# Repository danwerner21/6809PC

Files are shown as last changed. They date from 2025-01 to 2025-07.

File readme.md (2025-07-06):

# 6809PC
The 6809PC is a 6809 ATX format board with 512K RAM, 4K ROM, with a flexible programmable MMU, battery backed up RTC, 6551 UART, and 6 ISAish slots.  This computer will run the fantastic CUBIX operating system by Dave Dunfield.  

See this repo (https://github.com/danwerner21/CUBIX09) for ROM image and operating system.

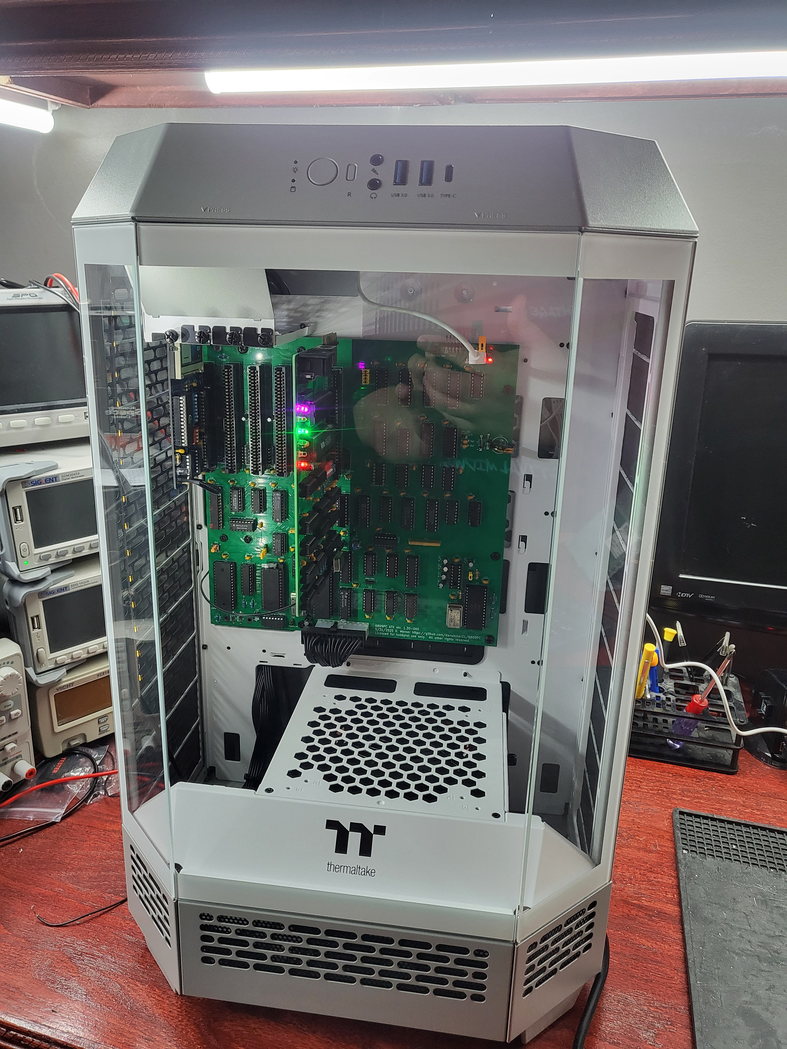
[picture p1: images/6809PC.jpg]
System


## BUGS
I have not built the 1.31 version, but it contains fixes for the only bug found in the 1.30 version which was in the ATX power switch circuit. The ICs in that circuit were not powered by standby power, they were powered by +5 which made them non-functional. Also the reset line on the ISA bus has the wrong polarity -- it should be active high.  There are no known remaining bugs in the 1.31 board.

### Jumper Settings
J1,J2,J5,J7,J9,J13 - ISA SLOT IRQ Selection
J11 - TTL Serial Port Connection
J12 - TTL Console Power

K1 - ROM BANK Selection (2-3 high bank, 1-2 Low Bank)
K2 - MMU Selection (1-2 Disable on int, 3-4 Clear Task register on int)

JP1 - Reset Swithc Connection
JP3 - CTS Pull Up Enable

P12 - Power Switch Connection
P15 - CPU Speed Selection
P18 - Serial Port Connection

### Building the system

### Default Memory Map
            $0000-$E000 - RAM
            $E000-$EFFF - Memory Mapped IO
            $F000-$FFFF - ROM

### Bill Of Materials
Reference|Value|Qty|Field1|Description
---------|-----|---|------|-----------
C1-C4,C17|22 uF|5||Polarized capacitor
C5-C16,C18-C27,C29-C33,C36-C54,C56,C58,C62|0.1 uF|49||Unpolarized capacitor
C28|1uF|1||Polarized capacitor
C35|10uF|1||Polarized capacitor
C57|0.01 uF|1||Unpolarized capacitor
C59,C60|15pf|2||Unpolarized capacitor
C61,C63-C66|1.0 uF|5||Polarized capacitor
D1,D2|1N4148|2||Diode
D3,D4|D|2||Diode
J1,J2,J5,J7,J9,J13|IRQ Selection|6||Generic connector, double row, 02x06, odd/even pin numbering scheme (row 1 odd numbers, row 2 even numbers), script generated (kicad-library-utils/schlib/autogen/connector/)
J3,J4,J6,J8,J10,J14|Bus_ISA_8bit|6||8-bit ISA-PC bus connector
J11|TTL SERIAL CONSOLE|1||Generic connector, single row, 01x06, script generated (kicad-library-utils/schlib/autogen/connector/)
J12|TTL CONSOLE PWR|1||Generic connector, single row, 01x02, script generated (kicad-library-utils/schlib/autogen/connector/)
JP1,JP3|JUMPER|2||-- mixed values --
K1|ROM SELECT|1||Generic connector, single row, 01x03, script generated (kicad-library-utils/schlib/autogen/connector/)
K2|MMU-INTA|1||Generic connector, single row, 01x03, script generated (kicad-library-utils/schlib/autogen/connector/)
P1|SHADOW ADDR|1||Generic connector, double row, 02x04, odd/even pin numbering scheme (row 1 odd numbers, row 2 even numbers), script generated (kicad-library-utils/schlib/autogen/connector/)
P11|CONN_10X2|1||Generic connector, double row, 02x10, odd/even pin numbering scheme (row 1 odd numbers, row 2 even numbers), script generated (kicad-library-utils/schlib/autogen/connector/)
P12|POWER_SW|1||Generic connector, single row, 01x02, script generated (kicad-library-utils/schlib/autogen/connector/)
P13|14.31818 MHz CLK|1||
P14|16.000Mhz|1||
P15|CPU CLOCK SPEED|1||Generic connector, double row, 02x04, odd/even pin numbering scheme (row 1 odd numbers, row 2 even numbers), script generated (kicad-library-utils/schlib/autogen/connector/)
P16|CONN_4|1||Generic connector, single row, 01x04, script generated (kicad-library-utils/schlib/autogen/connector/)
P17|1.8432 MHz CLK|1||
P18|SERIAL|1||Generic connector, double row, 02x05, odd/even pin numbering scheme (row 1 odd numbers, row 2 even numbers), script generated (kicad-library-utils/schlib/autogen/connector/)
R1,R3|10k|2||Resistor
R2|470|1||Resistor
R4,R7,R26|4.7K|3||Resistor
R5,R6,R8|1000|3||Resistor
RR1|2200|1||9 resistor network, star topology, bussed resistors, small symbol
RR2|22K|1||9 resistor network, star topology, bussed resistors, small symbol
SW1|POWER|1||Push button switch, generic, two pins
SW2|RESET|1||Push button switch, generic, two pins
U1|74LS04|1||Hex Inverter
U2,U34,U36,U39,U45,U46|74LS244|6||Octal Buffer and Line Driver With 3-State Output, active-low enables, non-inverting outputs
U3|74LS682|1||
U4|74LS86|1||Quad 2-input XOR
U5|74LS02|1||quad 2-input NOR gate
U6,U21|74LS00|2||quad 2-input NAND gate
U7,U10,U16|74LS32|3||Quad 2-input OR
U8|SRAM_512K|1||512K x 8 Low Power CMOS RAM, DIP-32
U9,U15|74LS08|2||Quad And2
U11|27C256|1||OTP EPROM 256 KiBit
U12,U22|74LS74|2||Dual D Flip-flop, Set & Reset
U17|74LS14|1||Hex inverter schmitt trigger
U18|74LS06|1||Inverter Open Collect
U19|74HCT14|1||Hex inverter schmitt trigger
U23|74LS688|1||8-bit magnitude comparator
U24,U42|74LS138|2||Decoder 3 to 8 active low outputs
U25-U28,U32,U41|74LS245|6||Octal BUS Transceivers, 3-State outputs
U29|DS1233|1||
U30|74LS163|1||Synchronous 4-bit programmable binary Counter
U31|74LS240|1||Octal Buffer and Line Driver With 3-State Output, active-low enables, inverting outputs
U33|MC68B09|1||8-Bit Microprocessing unit 2.0MHz, DIP-40
U35|74LS174|1||Hex D-type Flip-Flop, reset
U37|74LS157|1||Quad 2 to 1 line Multiplexer
U38|74LS374|1||8-bit Register, 3-state outputs
U40|SRAM-32K|1||256K (32K x 8) Static RAM, 70ns, DIP-28
U43,U44|74LS257|2||Quad 2 to 1 Multiplexer
U47|M6242|1||M6242
U48|G65SC51P|1||CMOS Asynchronous Communication Interface Adapter (ACIA), Serial UART, DIP-28
U49|MAX232|1||Dual RS232 driver/receiver, 5V supply, 120kb/s, 0C-70C
X1|RTC_OSC|1|32.768 KHz|Two pin crystal

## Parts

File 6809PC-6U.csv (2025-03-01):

Reference | Value | Datasheet | Footprint | Qty | DNP
C1,C2,C3,C4 | 22 uF | ~ | Custom:STD_DDW_PCAP | 4
C5,C6,C7,C8,C9,C10,C11,C12,C13,C14,C15,C16,C17,C18,C19,C20,C21,C22,C23,C24,C25,C26,C27,C29,C30,C31,C32,C33,C34,C36,C37,C38,C39,C40,C41,C42,C43,C44,C45,C46,C47,C48,C49,C50,C51,C52,C53,C54,C55,C56,C58,C62 | 0.1 uF | ~ | Custom:STD_DDW_CAP | 52
C28 | 1uF | ~ | Custom:STD_DDW_PCAP | 1
C35 | 10uF | ~ | Custom:STD_DDW_PCAP | 1
C57 | 0.01 uF | ~ | Custom:STD_DDW_CAP | 1
C59,C60 | 15pf | ~ | Custom:STD_DDW_CAP | 2
C61,C63,C64,C65,C66 | 1.0 uF | ~ | Custom:STD_DDW_PCAP | 5
C67 | 0.1µF | ~ | Custom:STD_DDW_CAP | 1
C68 | 10µF | ~ | Custom:STD_DDW_PCAP | 1
D1,D2 | 1N4148 | ~ | Custom:STD_DDW_DIODE | 2
D3,D4 | D | ~ | Custom:STD_DDW_DIODE | 2
D5,D6 | 1N4001 | http://www.vishay.com/docs/88503/1n4001.pdf | Custom:STD_DDW_DIODE | 2
J1,J2,J5,J7,J9 | IRQ Selection | ~ | Custom:STD_DDW_PINHEAD_V_2x06 | 5
J3,J4,J6,J8,J10 | Bus_ISA_8bit | https://en.wikipedia.org/wiki/Industry_Standard_Architecture | Custom:BUSPC_HOST | 5
J11 | TTL SERIAL CONSOLE | ~ | Custom:STD_DDW_PINHEAD_V_1x06 | 1
J12 | TTL CONSOLE PWR | ~ | Custom:STD_DDW_PINHEAD_V_1x02 | 1
J13 | KEYBOARD AND MOUSE | ~ | Custom:STD_DDW_PINHEAD_V_2x05 | 1
J14,J15 | VGA | ~ | -- mixed values -- | 2
J16 | Keyboard | http://service.powerdynamics.com/ec/Catalog17/Section%2011.pdf | Custom:PS2_DIN | 1
J17 | Mouse | http://service.powerdynamics.com/ec/Catalog17/Section%2011.pdf | Custom:PS2_DIN | 1
J18 | AUDIO OUT | ~ | Custom:STD_DDW_PINHEAD_V_1x02 | 1
J19 | TTL SERIAL 0 | ~ | Custom:STD_DDW_PINHEAD_V_1x06 | 1
J20 | TTL SER 0 PWR | ~ | Custom:STD_DDW_PINHEAD_V_1x02 | 1
J21 | TTL SERIAL 1 | ~ | Custom:STD_DDW_PINHEAD_V_1x06 | 1
J22 | TTL SER 1 PWR | ~ | Custom:STD_DDW_PINHEAD_V_1x02 | 1
JP1,JP3 | JUMPER | ~ | Custom:STD_DDW_PINHEAD_V_1x02 | 2
JP2 | CPU XTAL | ~ | Custom:STD_DDW_PINHEAD_V_1x02 | 1
JP4 | OPT1 | ~ | Custom:STD_DDW_PINHEAD_V_1x02 | 1
JP5 | OPT2 | ~ | Custom:STD_DDW_PINHEAD_V_1x02 | 1
K1 | EPROM/FLASH | ~ | Custom:STD_DDW_PINHEAD_V_1x03 | 1
K2 | CONN_3 | ~ | Custom:STD_DDW_PINHEAD_V_1x03 | 1
K3 | P Port Power | ~ | Custom:STD_DDW_PINHEAD_V_1x03 | 1
P1 | SHADOW ADDR | ~ | Custom:STD_DDW_PINHEAD_V_2x04 | 1
P11 | CONN_10X2 | ~ | Custom:ATXConnector | 1
P12 | POWER_SW | ~ | Custom:STD_DDW_PINHEAD_V_1x02 | 1
P13 | 14.31818 MHz CLK |  | Custom:STD_DDW_DIP14 | 1
P14 | 16.000Mhz |  | Custom:STD_DDW_DIP14 | 1
P15 | CPU CLOCK SPEED | ~ | Custom:STD_DDW_PINHEAD_V_2x04 | 1
P16 | CONN_4 | ~ | Custom:STD_DDW_PINHEAD_V_1x04 | 1
P17 | 1.8432 MHz CLK |  | Custom:STD_DDW_DIP14 | 1
P18 | SERIAL | ~ | Custom:STD_DDW_PINHEAD_V_2x05 | 1
P19 | VIA OUTPUT | ~ | Custom:STD_DDW_PINHEAD_V_2x08 | 1
P20 | PARALLEL | ~ | Custom:STD_DDW_PINHEAD_V_2x13 | 1
R1,R3 | 10k | ~ | Custom:STD_DDW_RESISTOR | 2
R2 | 470 | ~ | Custom:STD_DDW_RESISTOR | 1
R4,R7 | 4.7K | ~ | Custom:STD_DDW_RESISTOR | 2
R5,R6 | 1000 | ~ | Custom:STD_DDW_RESISTOR | 2
R8,R10,R12 | 390Ω | ~ | Custom:STD_DDW_RESISTOR | 3
R9,R11,R13 | 820Ω | ~ | Custom:STD_DDW_RESISTOR | 3
R14,R15,R20,R21 | 120Ω | ~ | Custom:STD_DDW_RESISTOR | 4
R16,R18 | 2.2KΩ | ~ | Custom:STD_DDW_RESISTOR | 2
R17,R19,RN1 | 1KΩ | -- mixed values -- | -- mixed values -- | 3
R22 | 270Ω | ~ | Custom:STD_DDW_RESISTOR | 1
R23 | 150Ω | ~ | Custom:STD_DDW_RESISTOR | 1
R24,R25,RR2 | 22K | -- mixed values -- | -- mixed values -- | 3
RR1 | 2200 | http://www.vishay.com/docs/31509/csc.pdf | Custom:STD_DDW_SIP10 | 1
SW1 | POWER | ~ | Custom:STD_DDW_TACTSW | 1
SW2 | MOM CNCT | ~ | Custom:STD_DDW_TACTSW | 1
U1,U20 | 74LS04 | http://www.ti.com/lit/gpn/sn74LS04 | Custom:STD_DDW_DIP14 | 2
U2,U34,U36,U39,U45,U46,U56 | 74LS244 | http://www.ti.com/lit/ds/symlink/sn74ls244.pdf | Custom:STD_DDW_DIP20 | 7
U3 | 74LS682 |  | Custom:STD_DDW_DIP20 | 1
U4 | 74LS86 | 74xx/74ls86.pdf | Custom:STD_DDW_DIP14 | 1
U5 | 74LS02 | http://www.ti.com/lit/gpn/sn74ls02 | Custom:STD_DDW_DIP14 | 1
U6,U21 | 74LS00 | http://www.ti.com/lit/gpn/sn74ls00 | Custom:STD_DDW_DIP14 | 2
U7,U10,U11,U12,U16 | 74LS32 | http://www.ti.com/lit/gpn/sn74LS32 | Custom:STD_DDW_DIP14 | 5
U8 | SRAM_512K | https://www.alliancememory.com/wp-content/uploads/pdf/AS6C4008.pdf | Custom:STD_DDW_DIP32 | 1
U9 | 29F040 | http://ww1.microchip.com/downloads/en/DeviceDoc/25022B.pdf | Custom:STD_DDW_DIP32 | 1
U13,U14 | 74LS07 | www.ti.com/lit/ds/symlink/sn74ls07.pdf | Custom:STD_DDW_DIP14 | 2
U15 | 74LS08 | http://www.ti.com/lit/gpn/sn74LS08 | Custom:STD_DDW_DIP14 | 1
U17 | 74LS14 | http://www.ti.com/lit/gpn/sn74LS14 | Custom:STD_DDW_DIP14 | 1
U18 | 74LS06 | http://www.ti.com/lit/gpn/sn74LS06 | Custom:STD_DDW_DIP14 | 1
U19 | 74HCT14 | http://www.ti.com/lit/gpn/sn74LS14 | Custom:STD_DDW_DIP14 | 1
U22 | 74LS74 | 74xx/74hc_hct74.pdf | Custom:STD_DDW_DIP14 | 1
U23 | 74LS688 | http://www.ti.com/lit/gpn/sn74LS688 | Custom:STD_DDW_DIP20 | 1
U24,U42 | 74LS138 | http://www.ti.com/lit/gpn/sn74LS138 | Custom:STD_DDW_DIP16 | 2
U25,U26,U27,U28,U32,U41 | 74LS245 | http://www.ti.com/lit/gpn/sn74LS245 | Custom:STD_DDW_DIP20 | 6
U29 | DS1233 | ~ | Custom:STD_DDW_TO92 | 1
U30 | 74LS163 | http://www.ti.com/lit/gpn/sn74LS163 | Custom:STD_DDW_DIP16 | 1
U31 | 74LS240 | http://www.ti.com/lit/ds/symlink/sn74ls240.pdf | Custom:STD_DDW_DIP20 | 1
U33 | MC68B09 | http://pdf.datasheetcatalog.com/datasheet/motorola/MC68B09S.pdf | Custom:STD_DDW_DIP40 | 1
U35 | 74LS174 | http://www.ti.com/lit/gpn/sn74LS174 | Custom:STD_DDW_DIP16 | 1
U37 | 74LS157 | http://www.ti.com/lit/gpn/sn74LS157 | Custom:STD_DDW_DIP16 | 1
U38 | 74LS374 | http://www.ti.com/lit/gpn/sn74LS374 | Custom:STD_DDW_DIP20 | 1
U40 | SRAM-32K | https://ecee.colorado.edu/~mcclurel/Cypress_SRAM_CY62256.pdf | Custom:STD_DDW_DIP28_SKINNY | 1
U43,U44 | 74LS257 | http://www.ti.com/lit/gpn/sn74LS257 | Custom:STD_DDW_DIP16 | 2
U47 | ~ |  | Custom:STD_DDW_DIP18 | 1
U48 | G65SC51P | http://www.westerndesigncenter.com/wdc/documentation/w65c51n.pdf | Custom:STD_DDW_DIP28 | 1
U49 | MAX232 | http://www.ti.com/lit/ds/symlink/max232.pdf | Custom:STD_DDW_DIP16 | 1
U50,U52 | 74HC595 | http://www.ti.com/lit/ds/symlink/sn74hc595.pdf | Custom:STD_DDW_DIP16 | 2
U51,U53 | 74HC165 | https://assets.nexperia.com/documents/data-sheet/74HC_HCT165.pdf | Custom:STD_DDW_DIP16 | 2
U54,U55 | ESP32_MODULE |  | Custom:ESP32_Module | 2
U57,U58 | G65SC22P | http://www.westerndesigncenter.com/wdc/documentation/w65c22.pdf | Custom:STD_DDW_DIP40 | 2
X1 | RTC_OSC | ~ | Custom:DDW_STD_RTCCRYSTAL | 1

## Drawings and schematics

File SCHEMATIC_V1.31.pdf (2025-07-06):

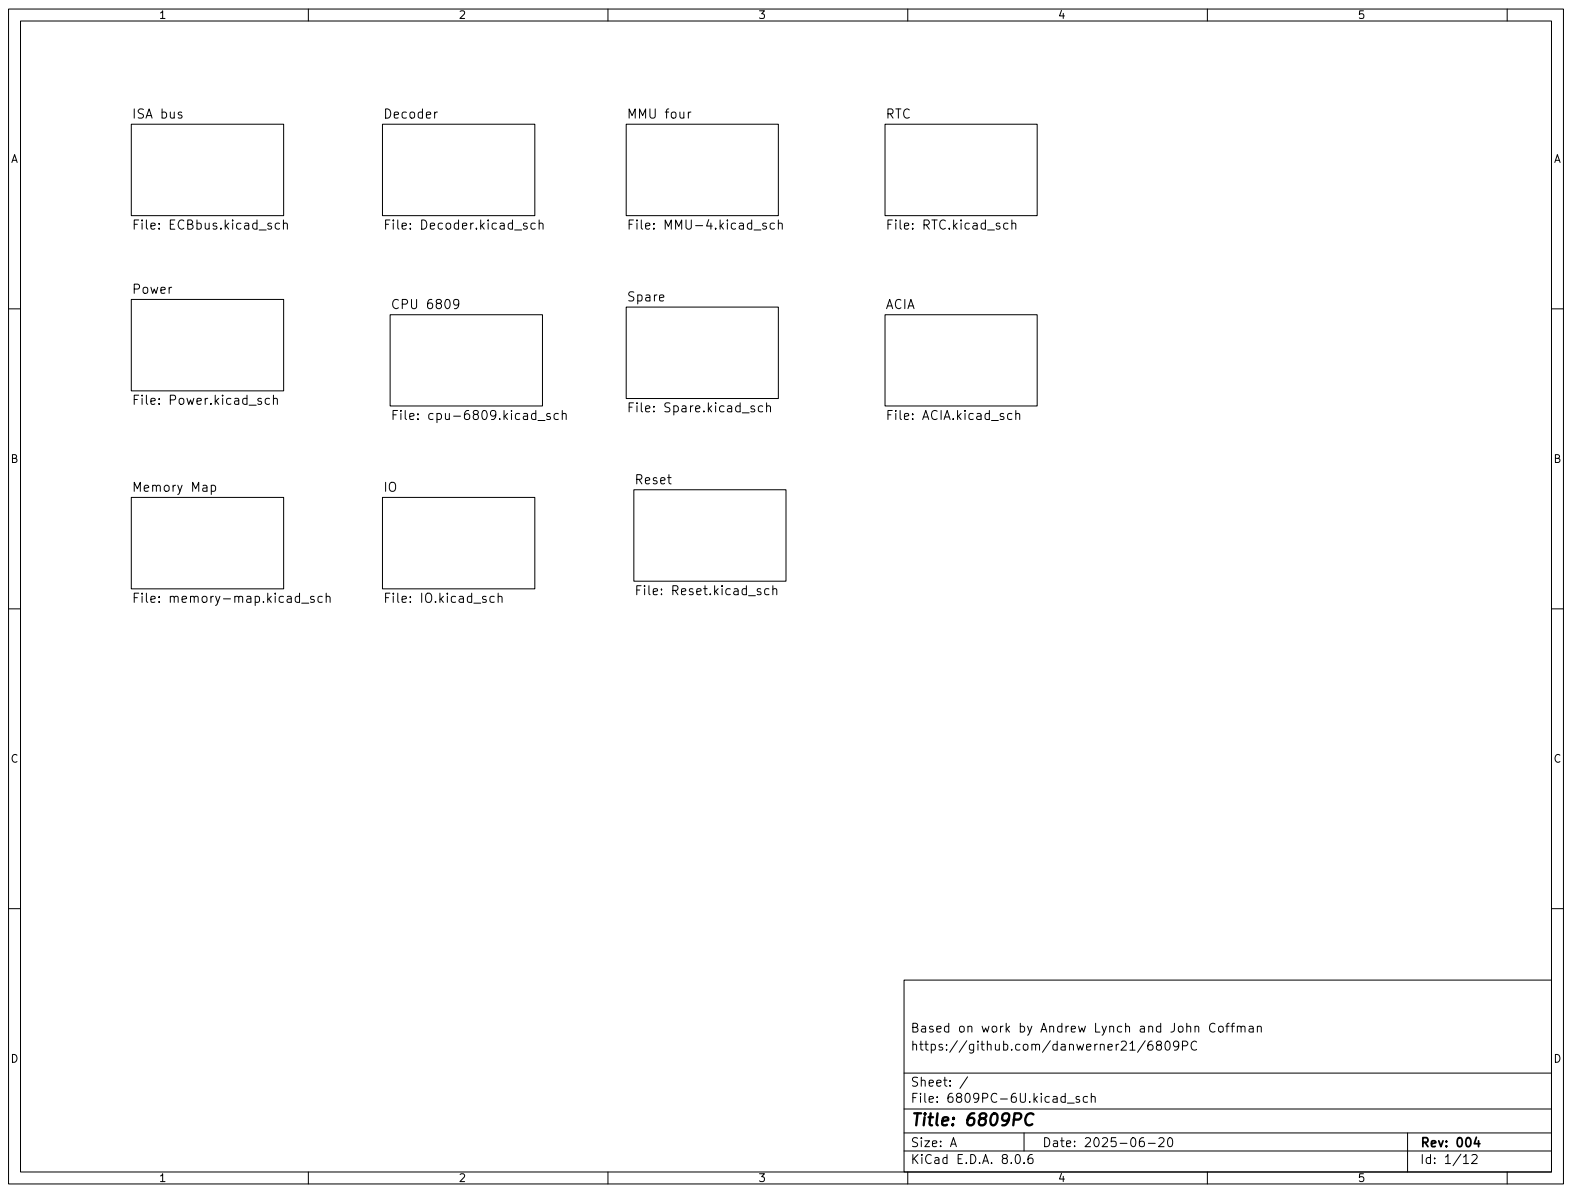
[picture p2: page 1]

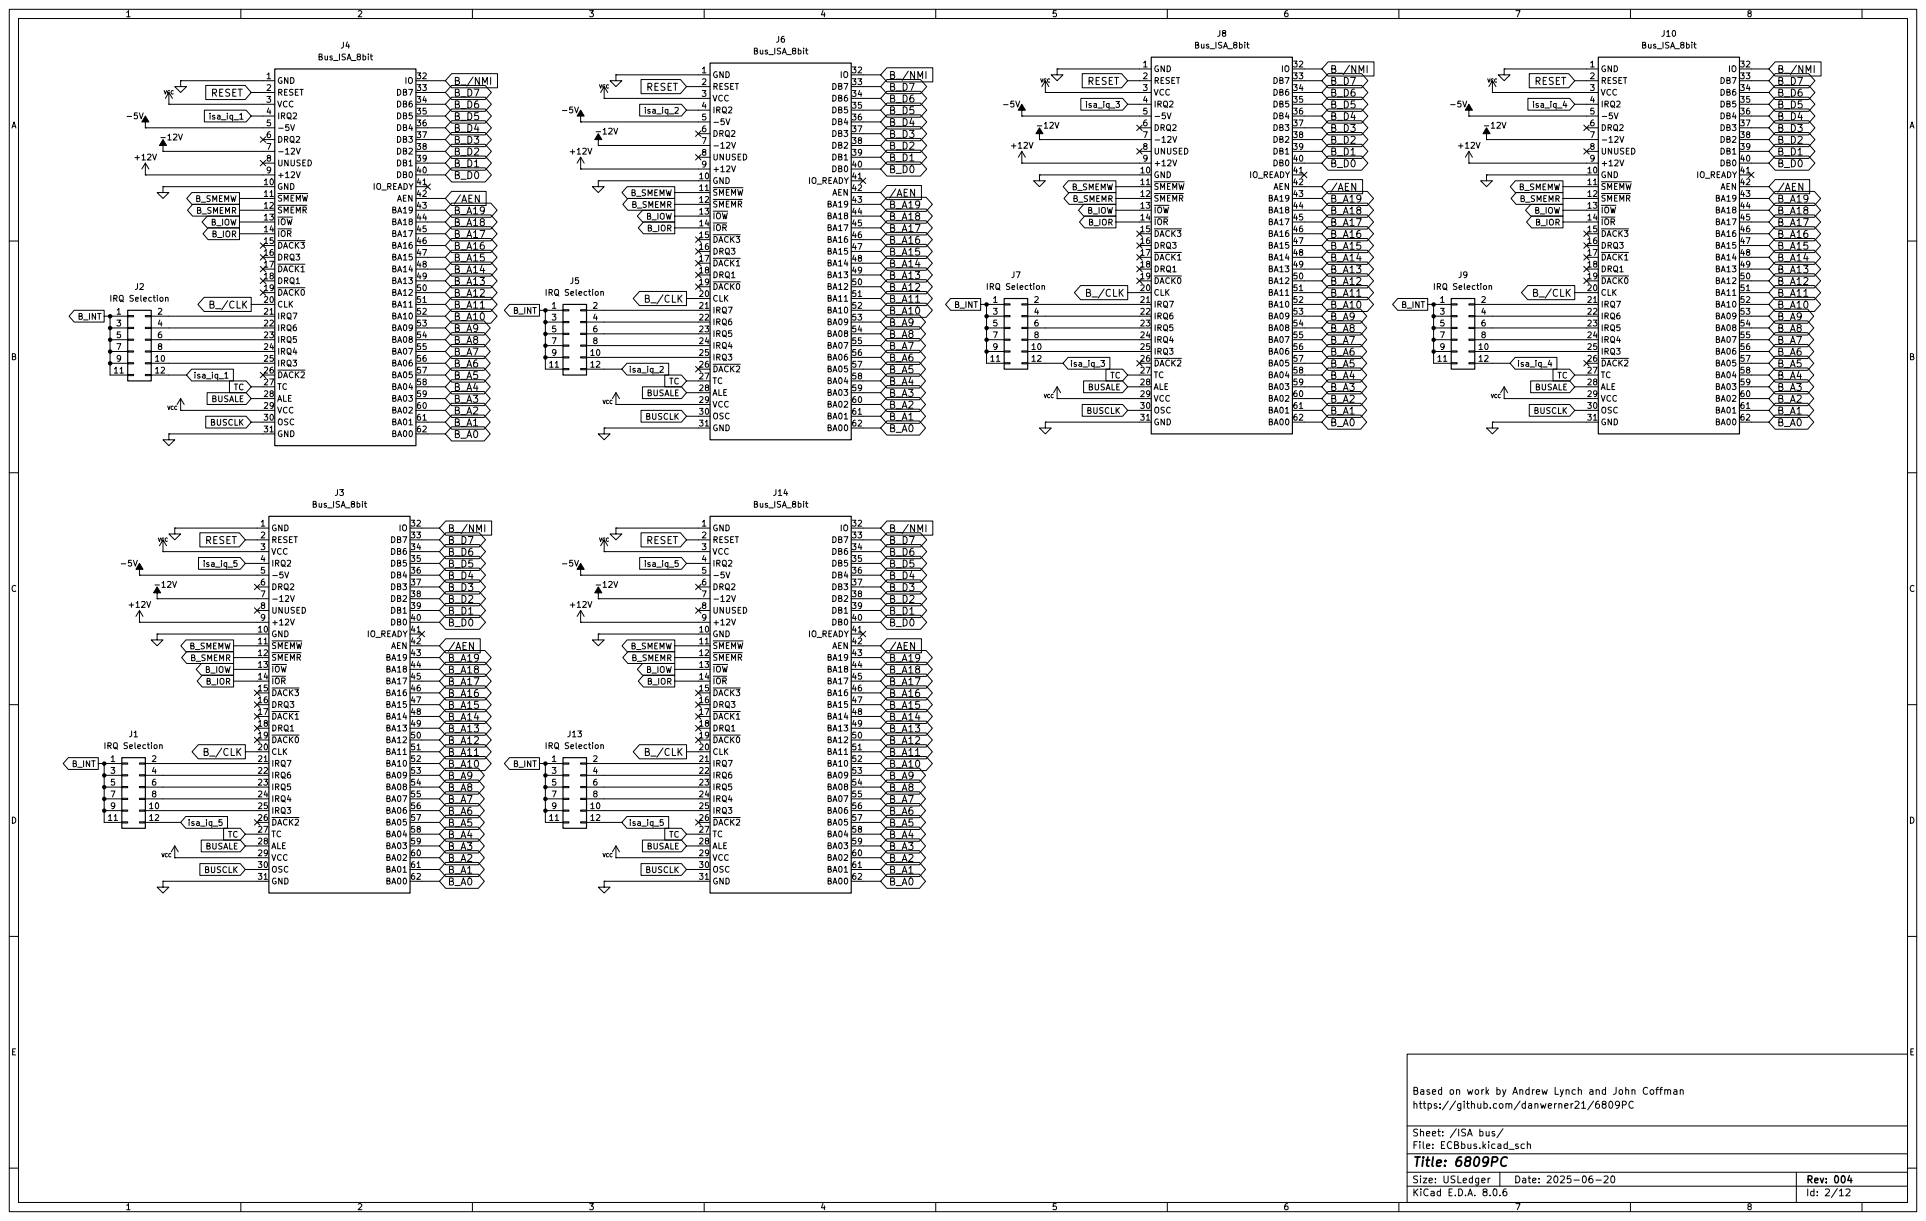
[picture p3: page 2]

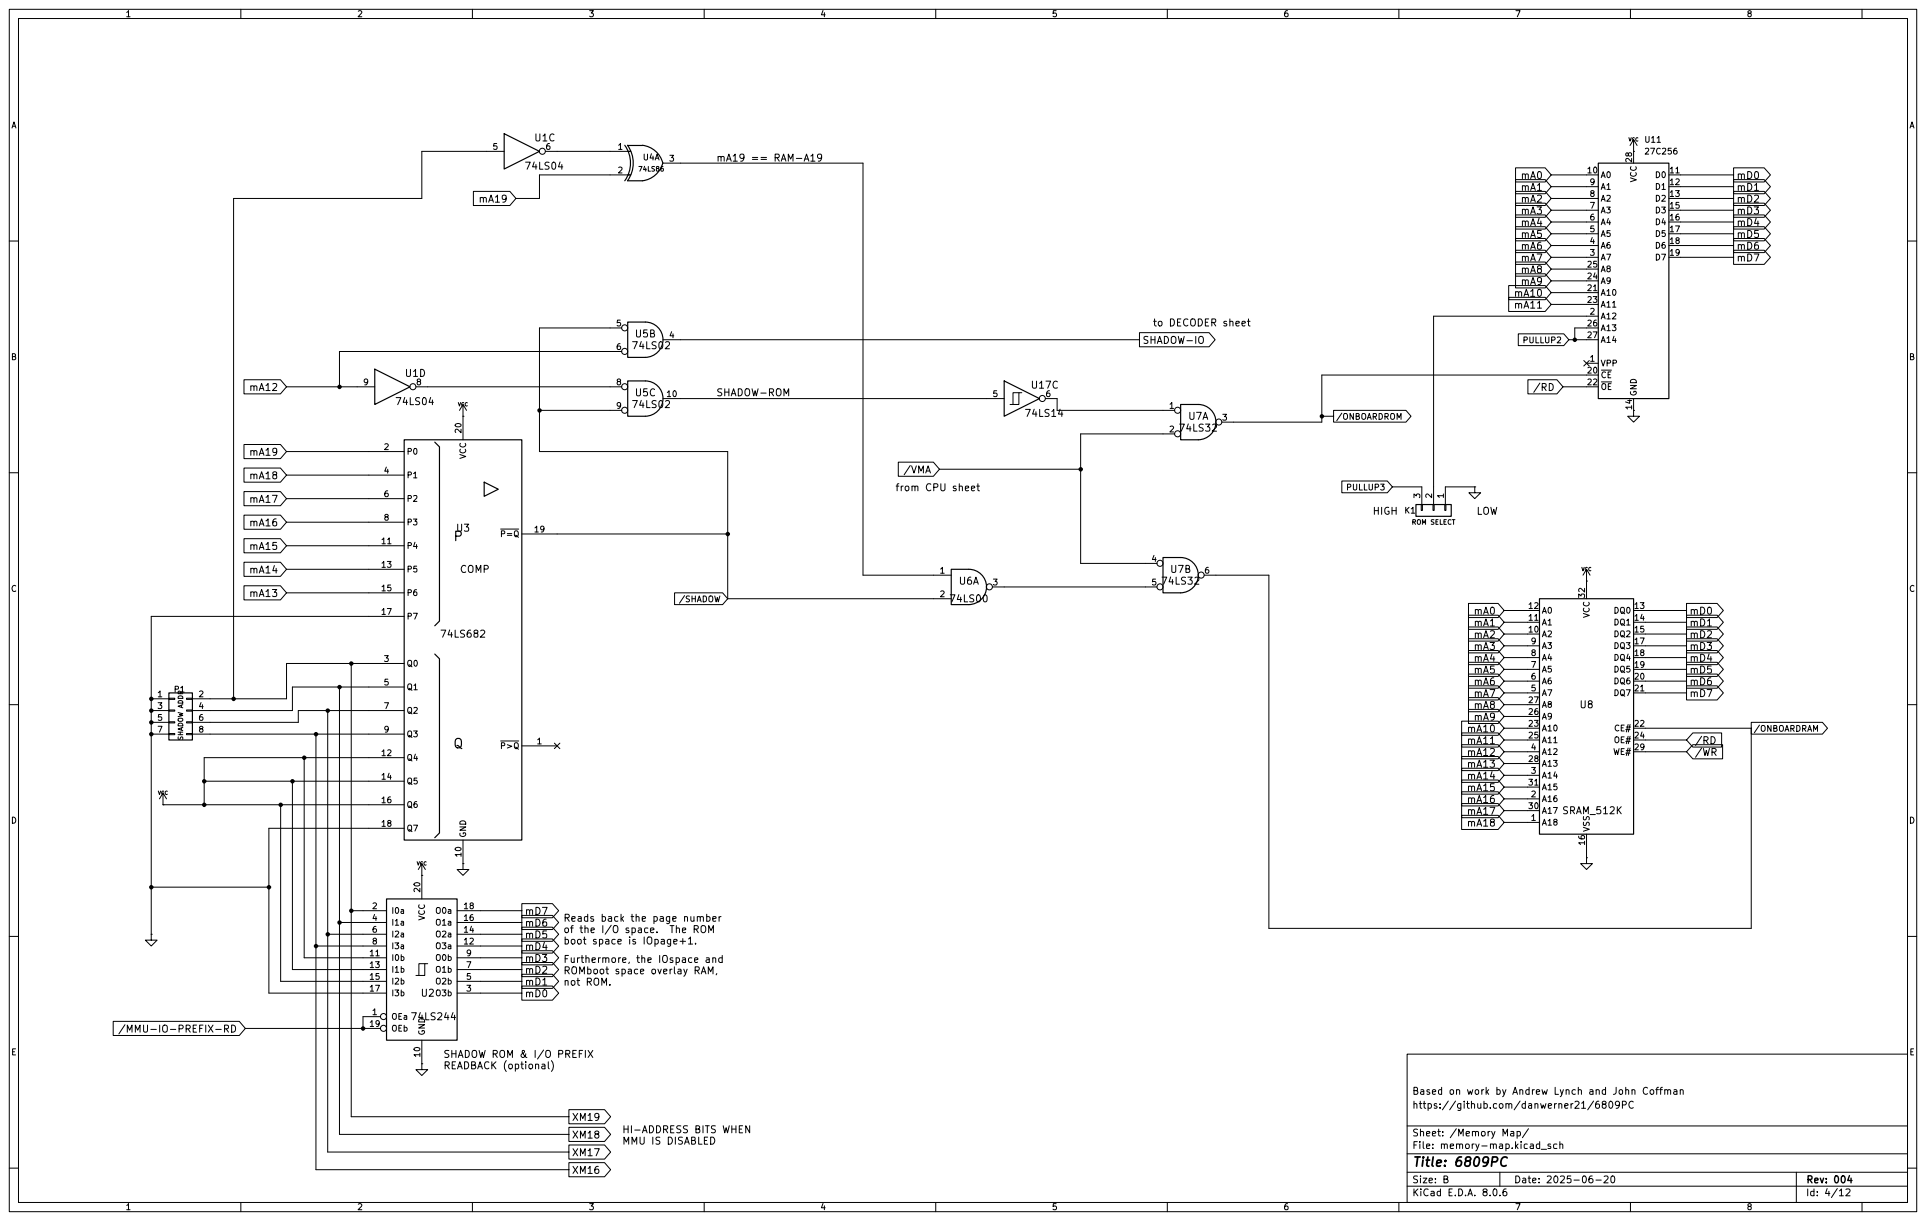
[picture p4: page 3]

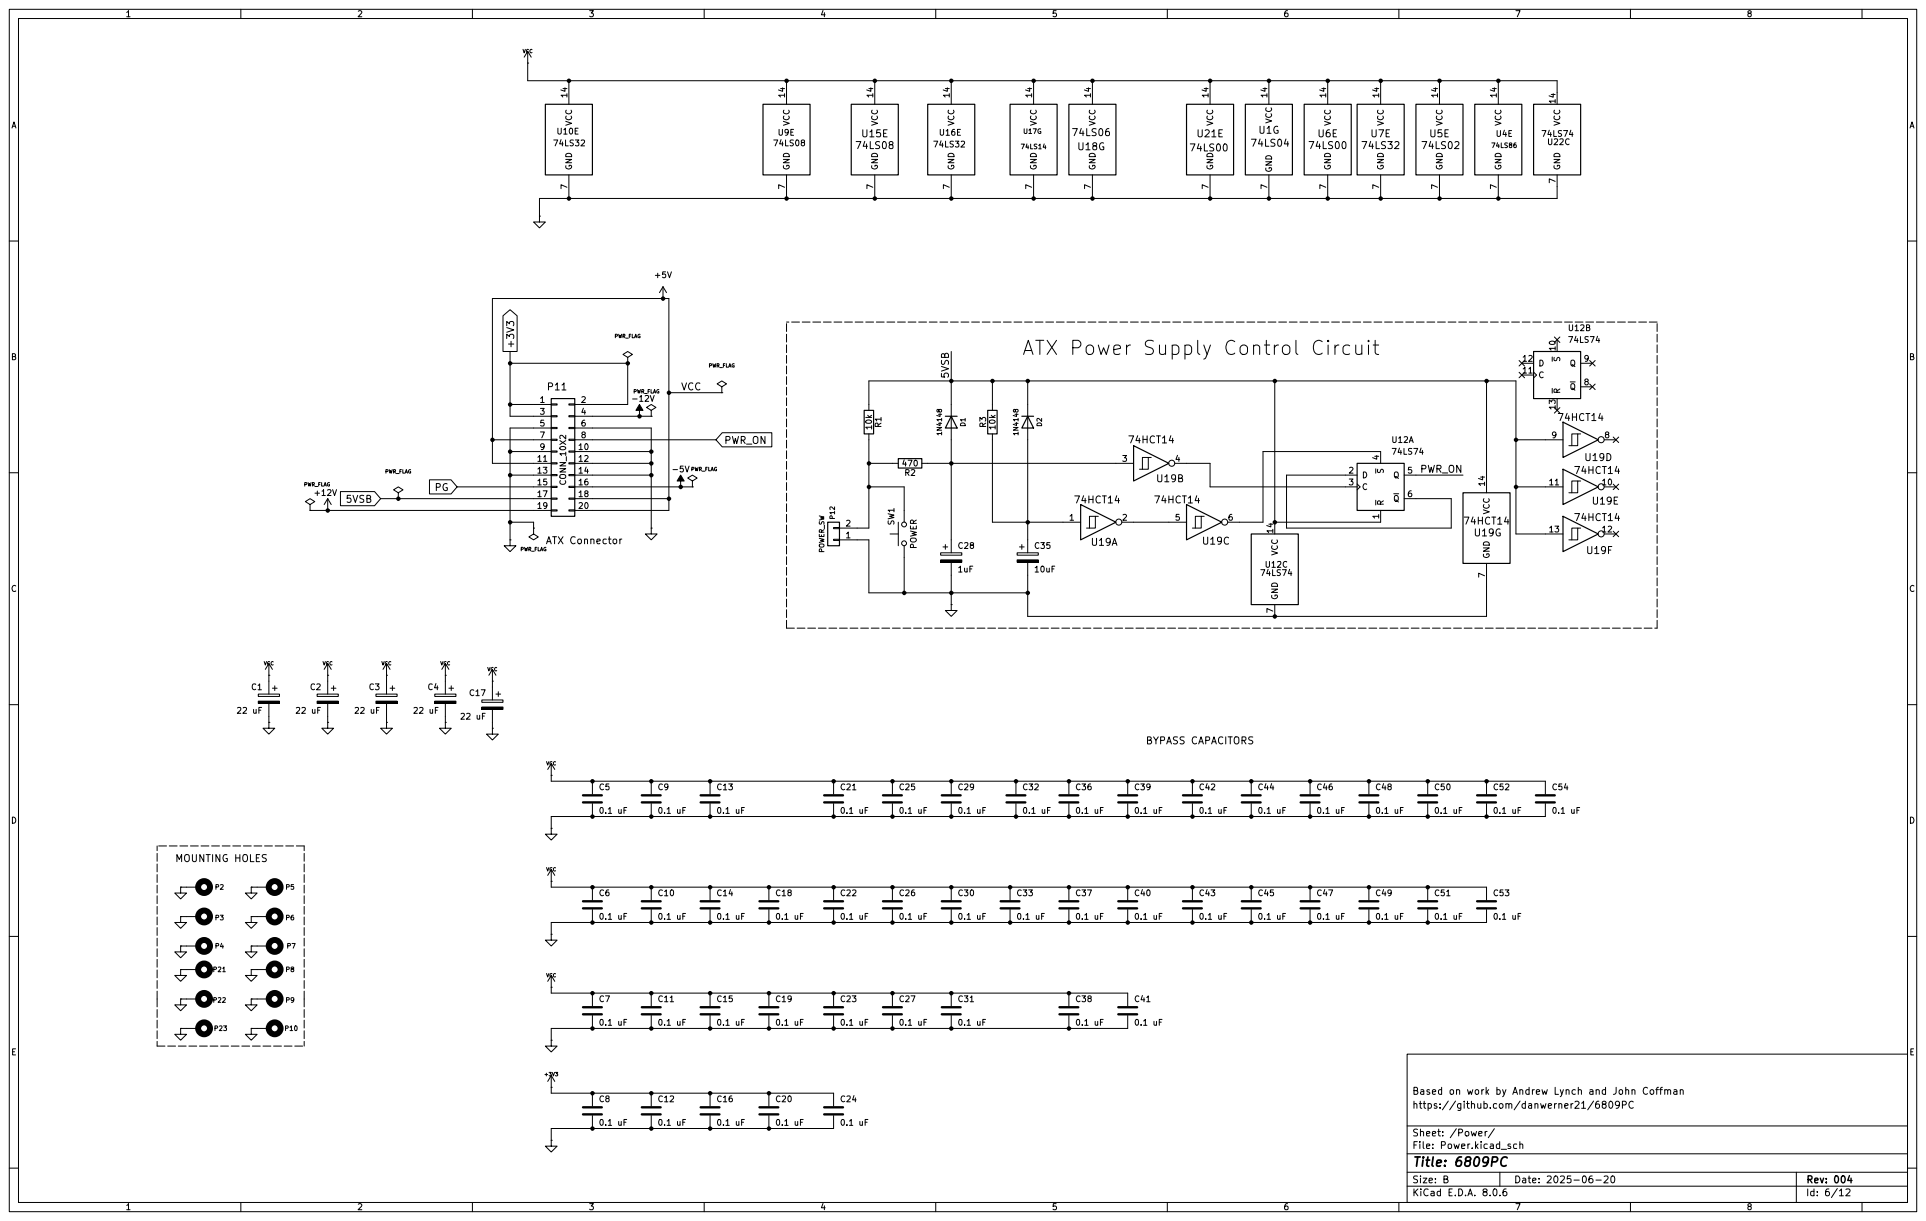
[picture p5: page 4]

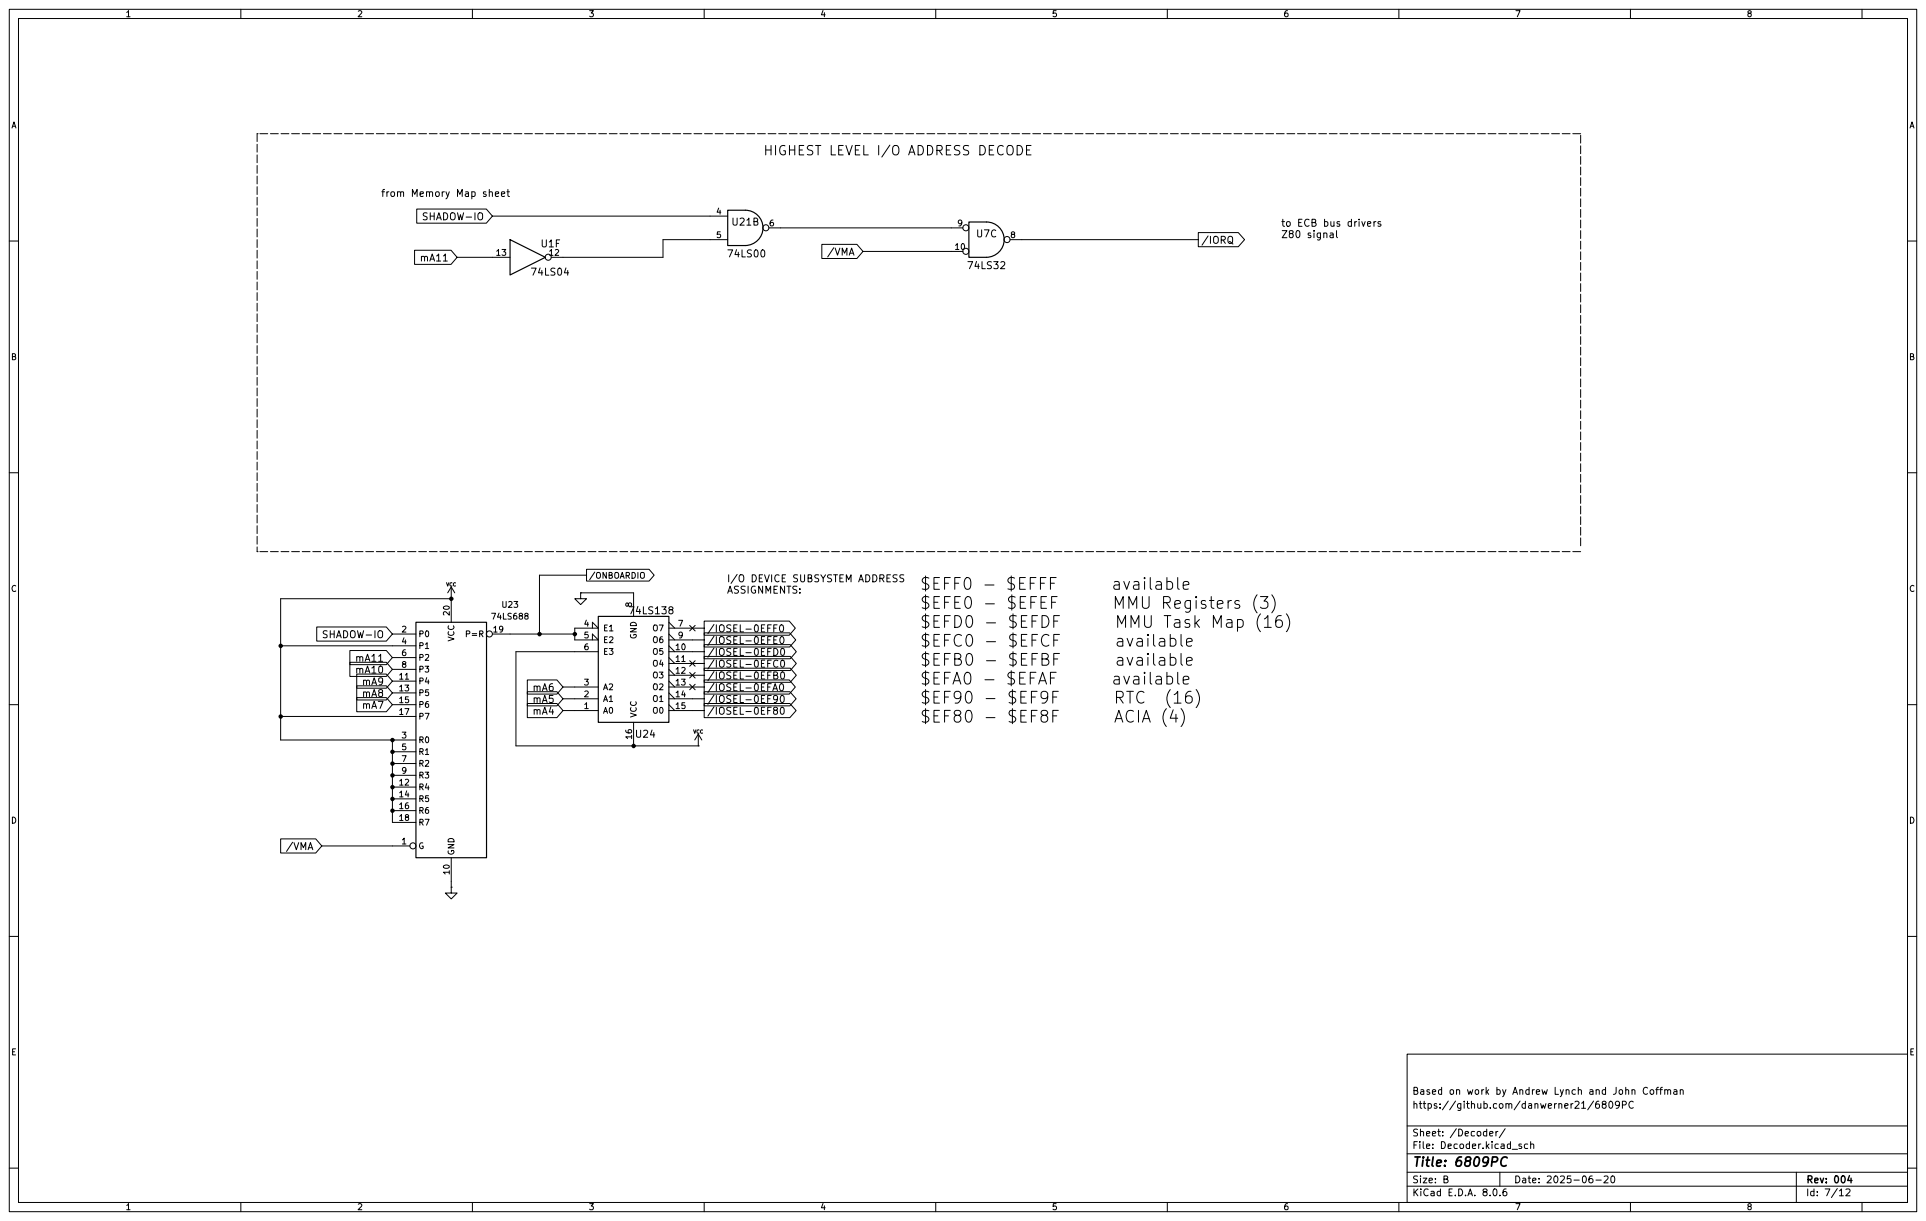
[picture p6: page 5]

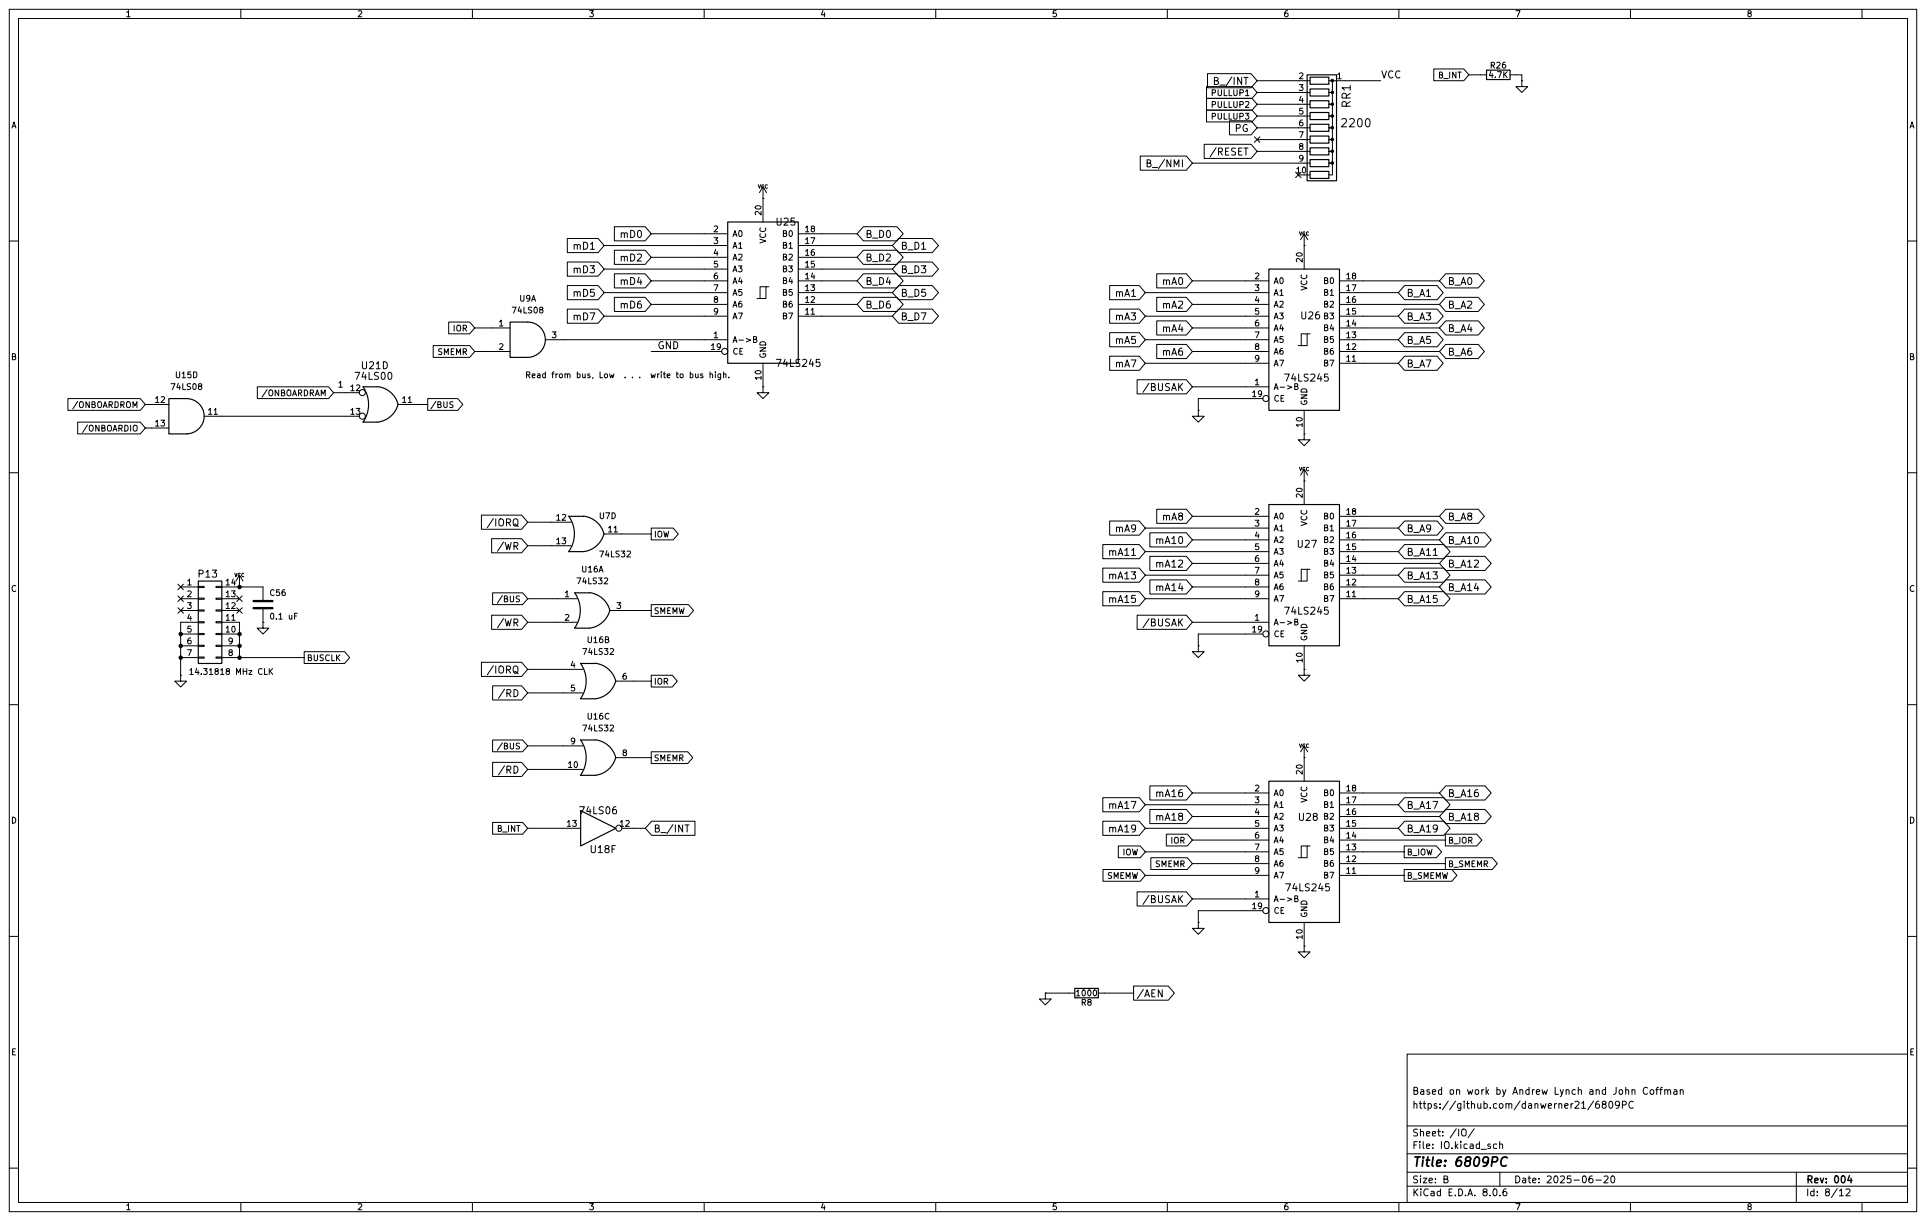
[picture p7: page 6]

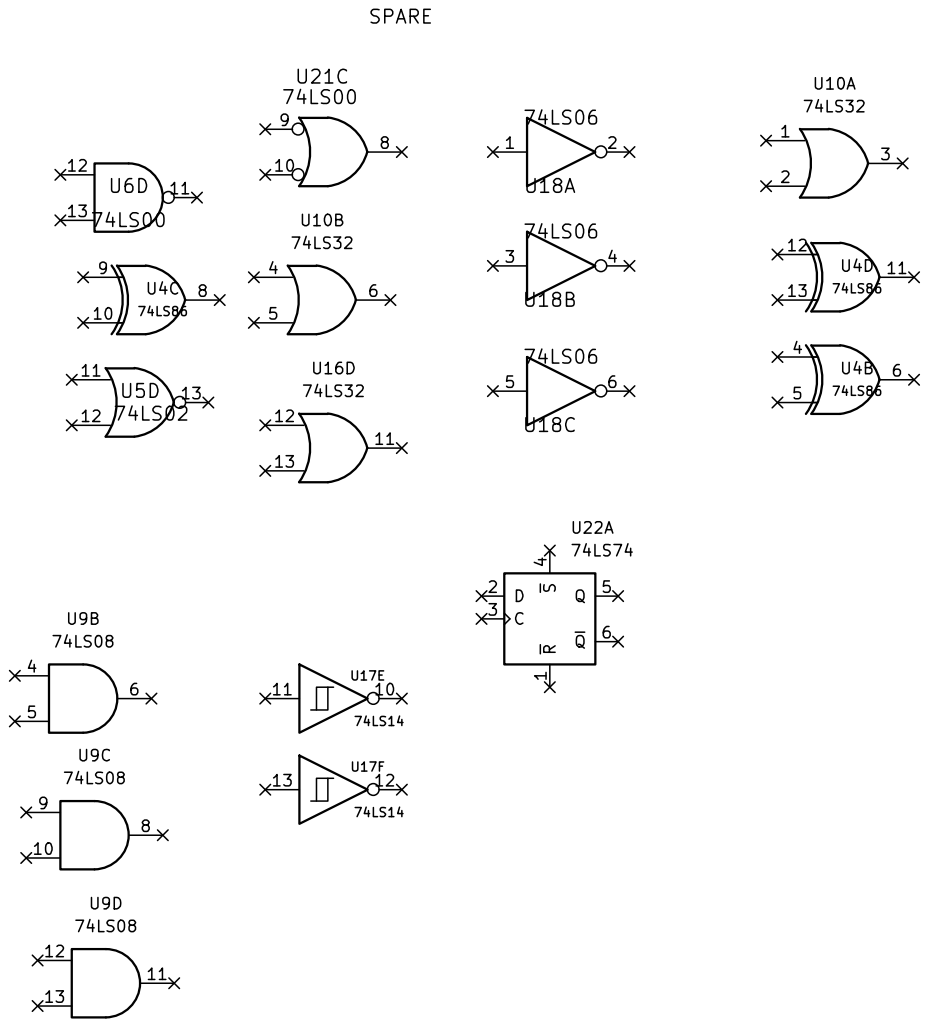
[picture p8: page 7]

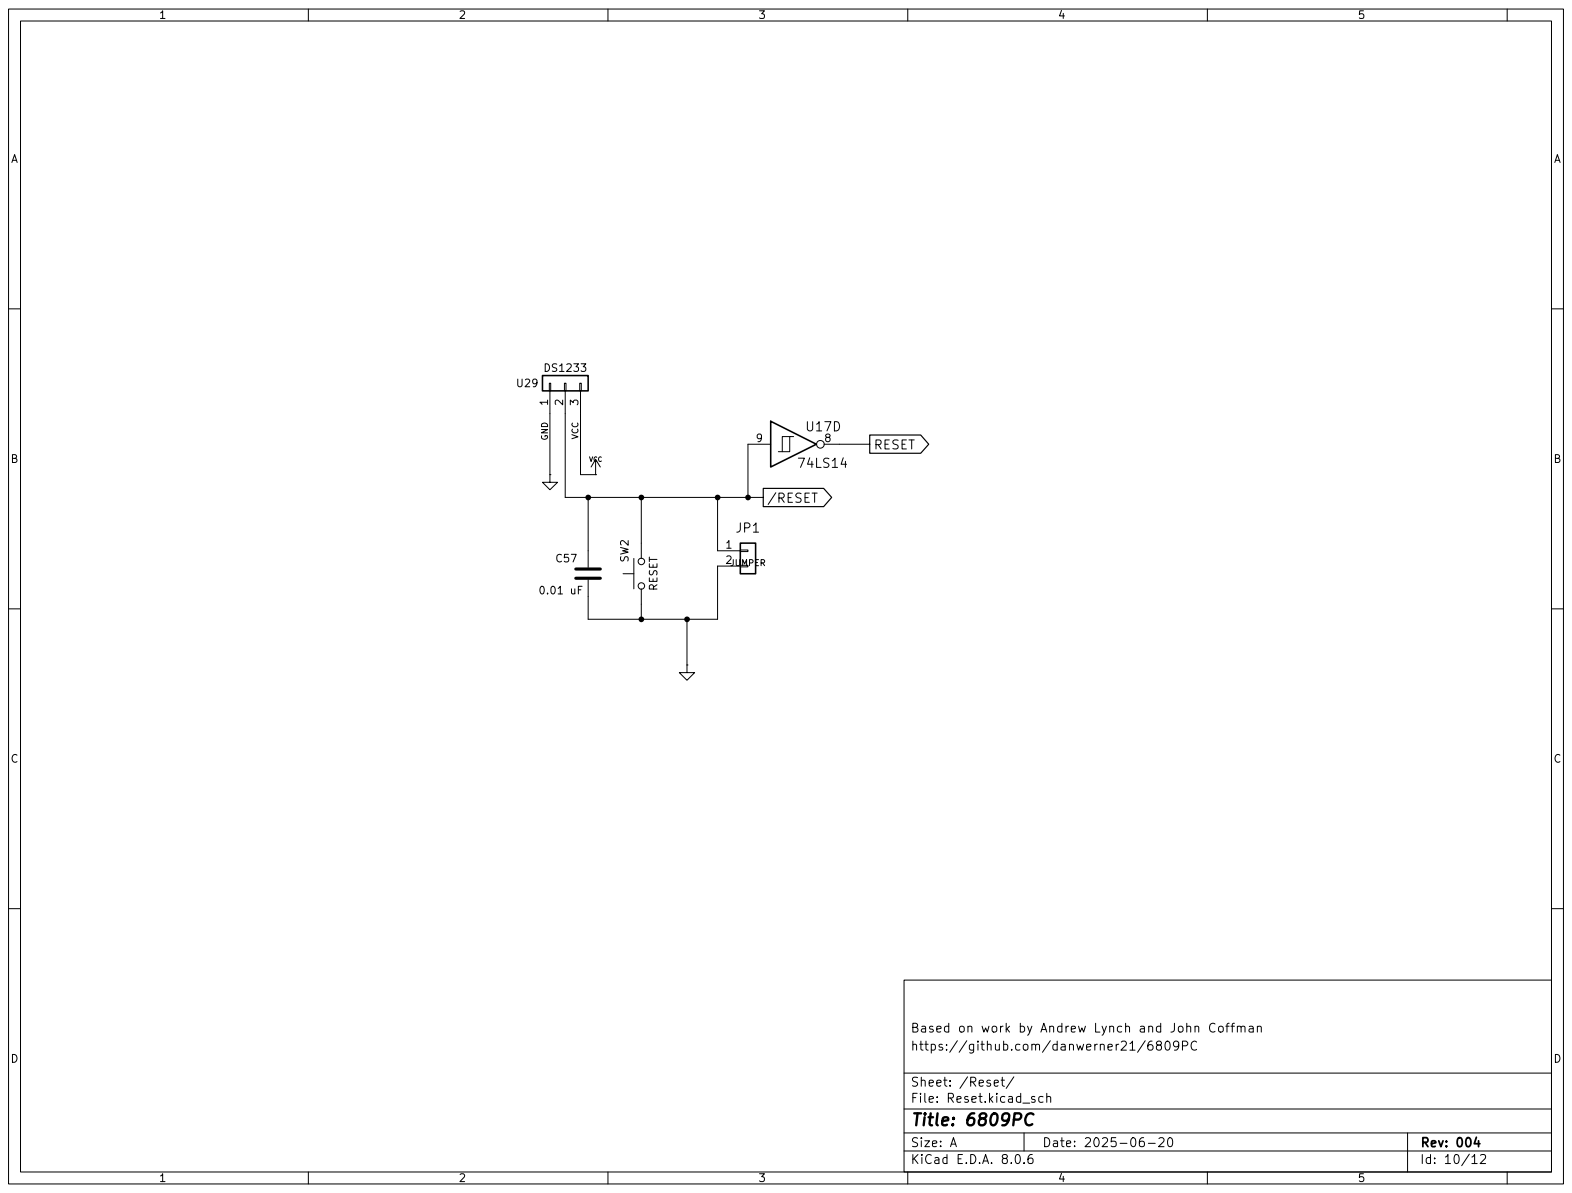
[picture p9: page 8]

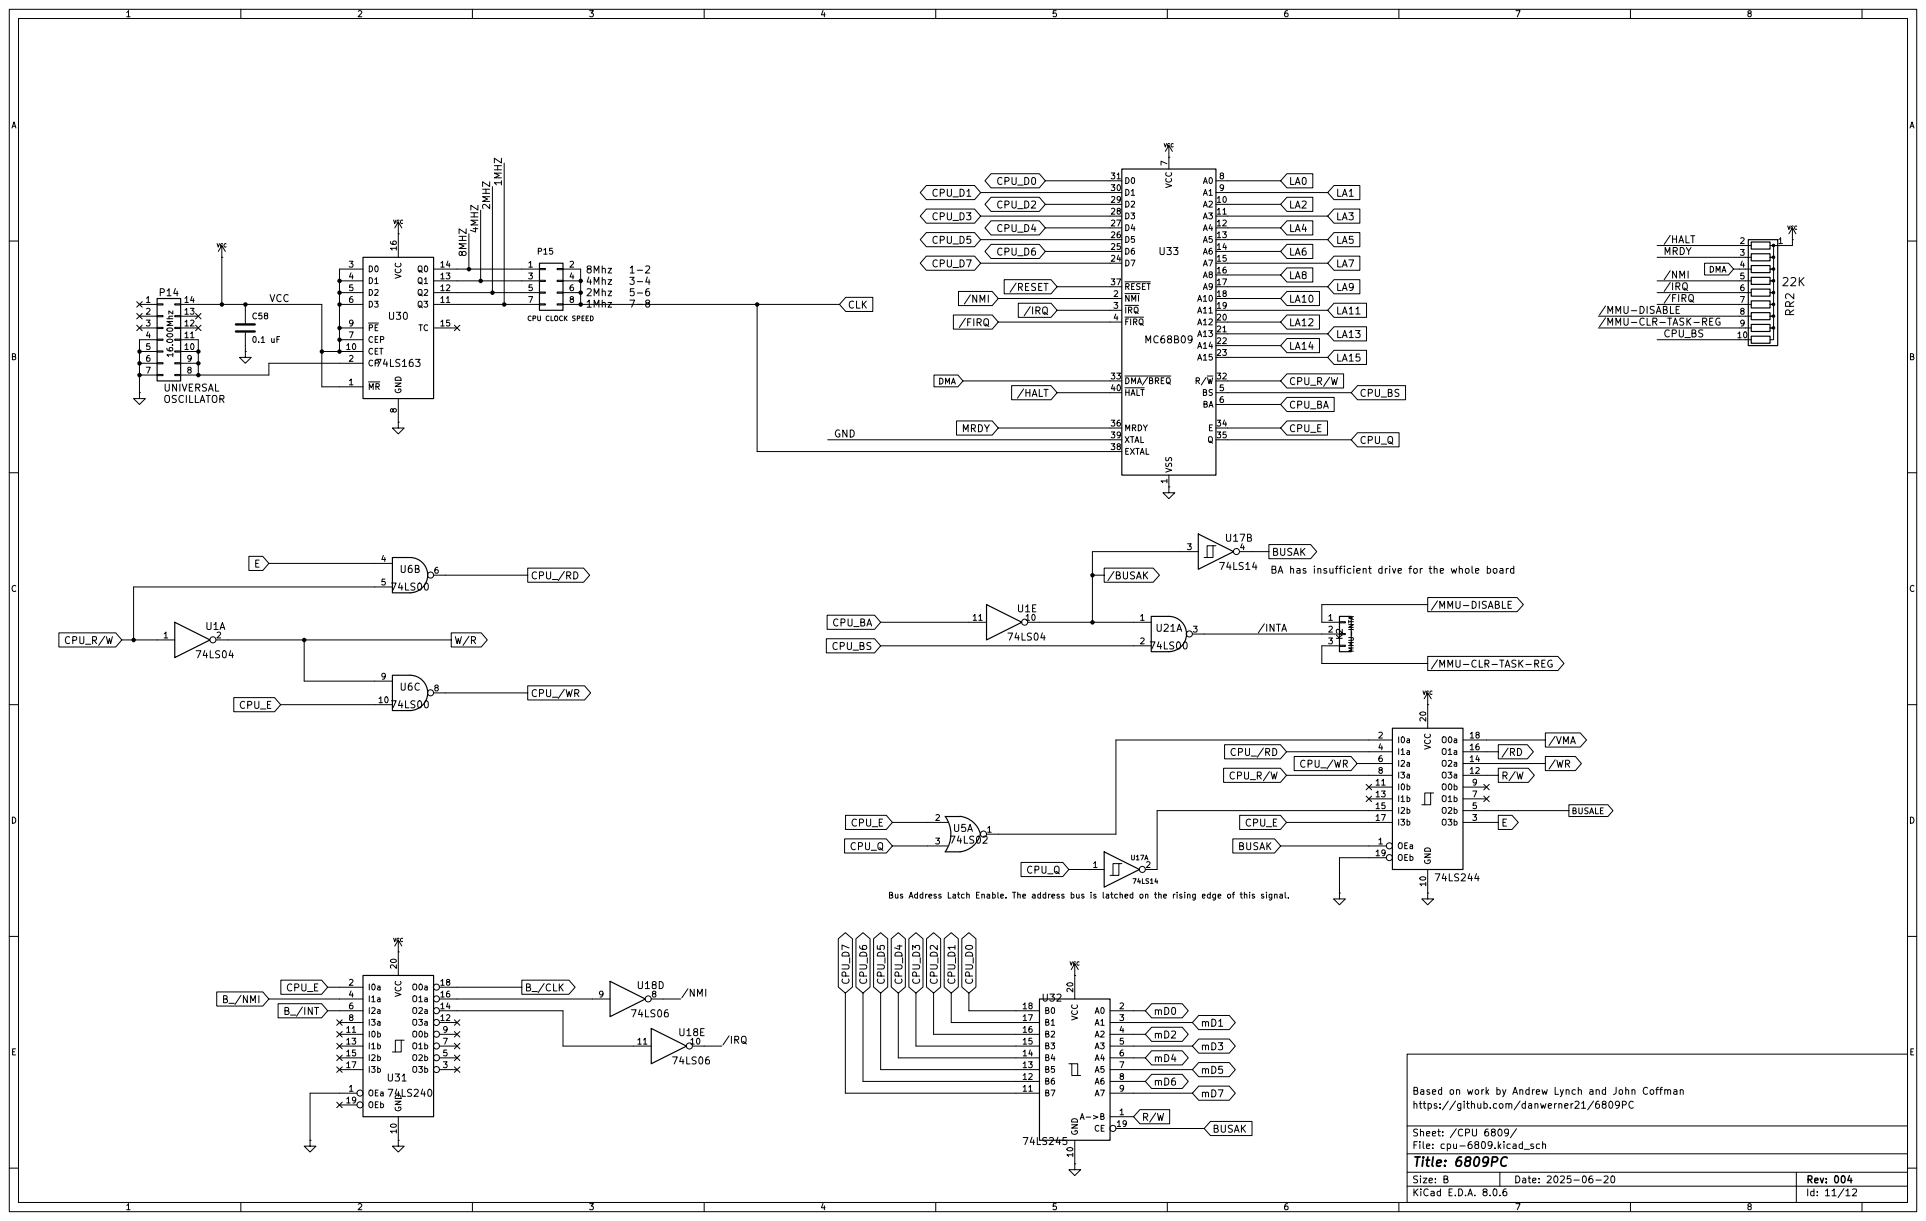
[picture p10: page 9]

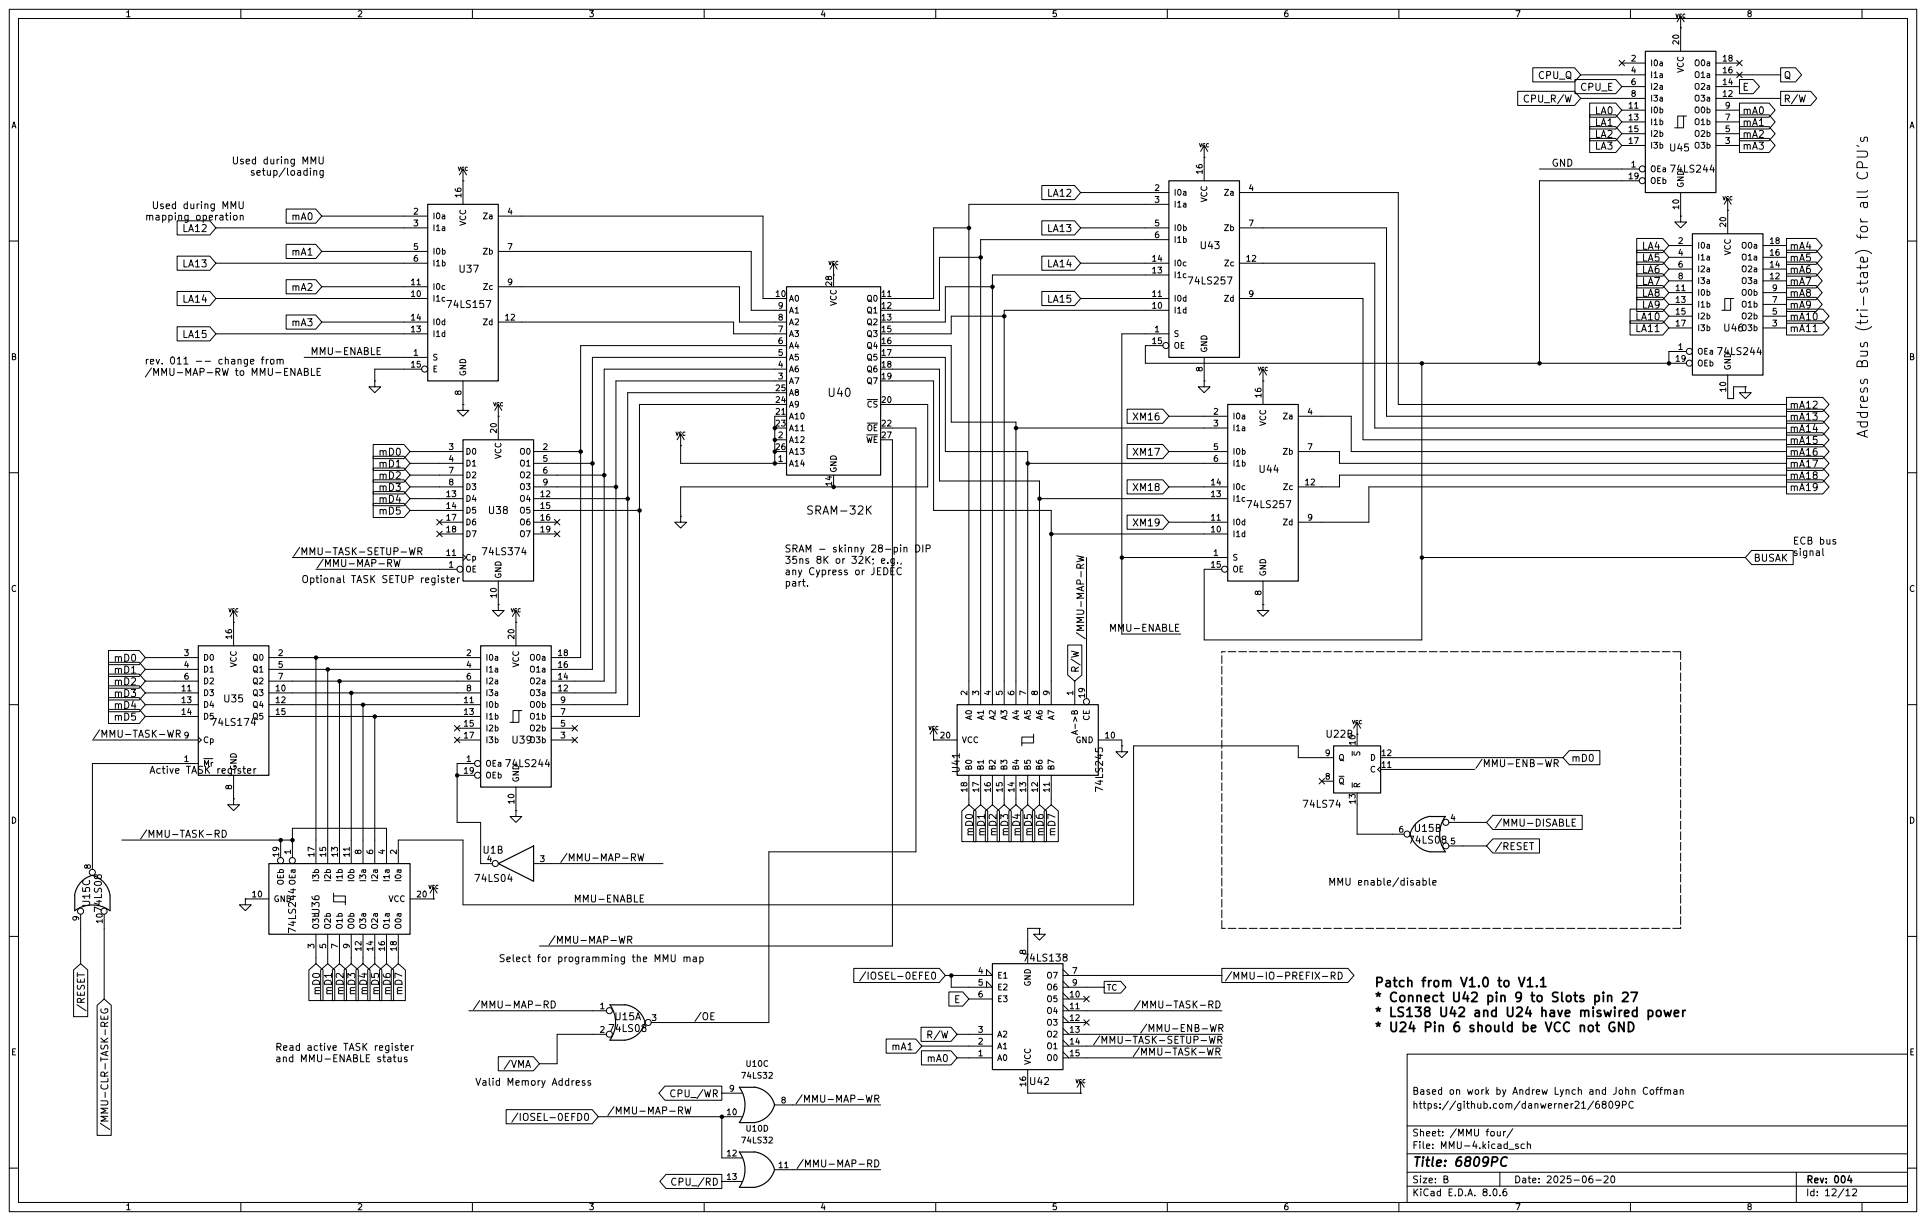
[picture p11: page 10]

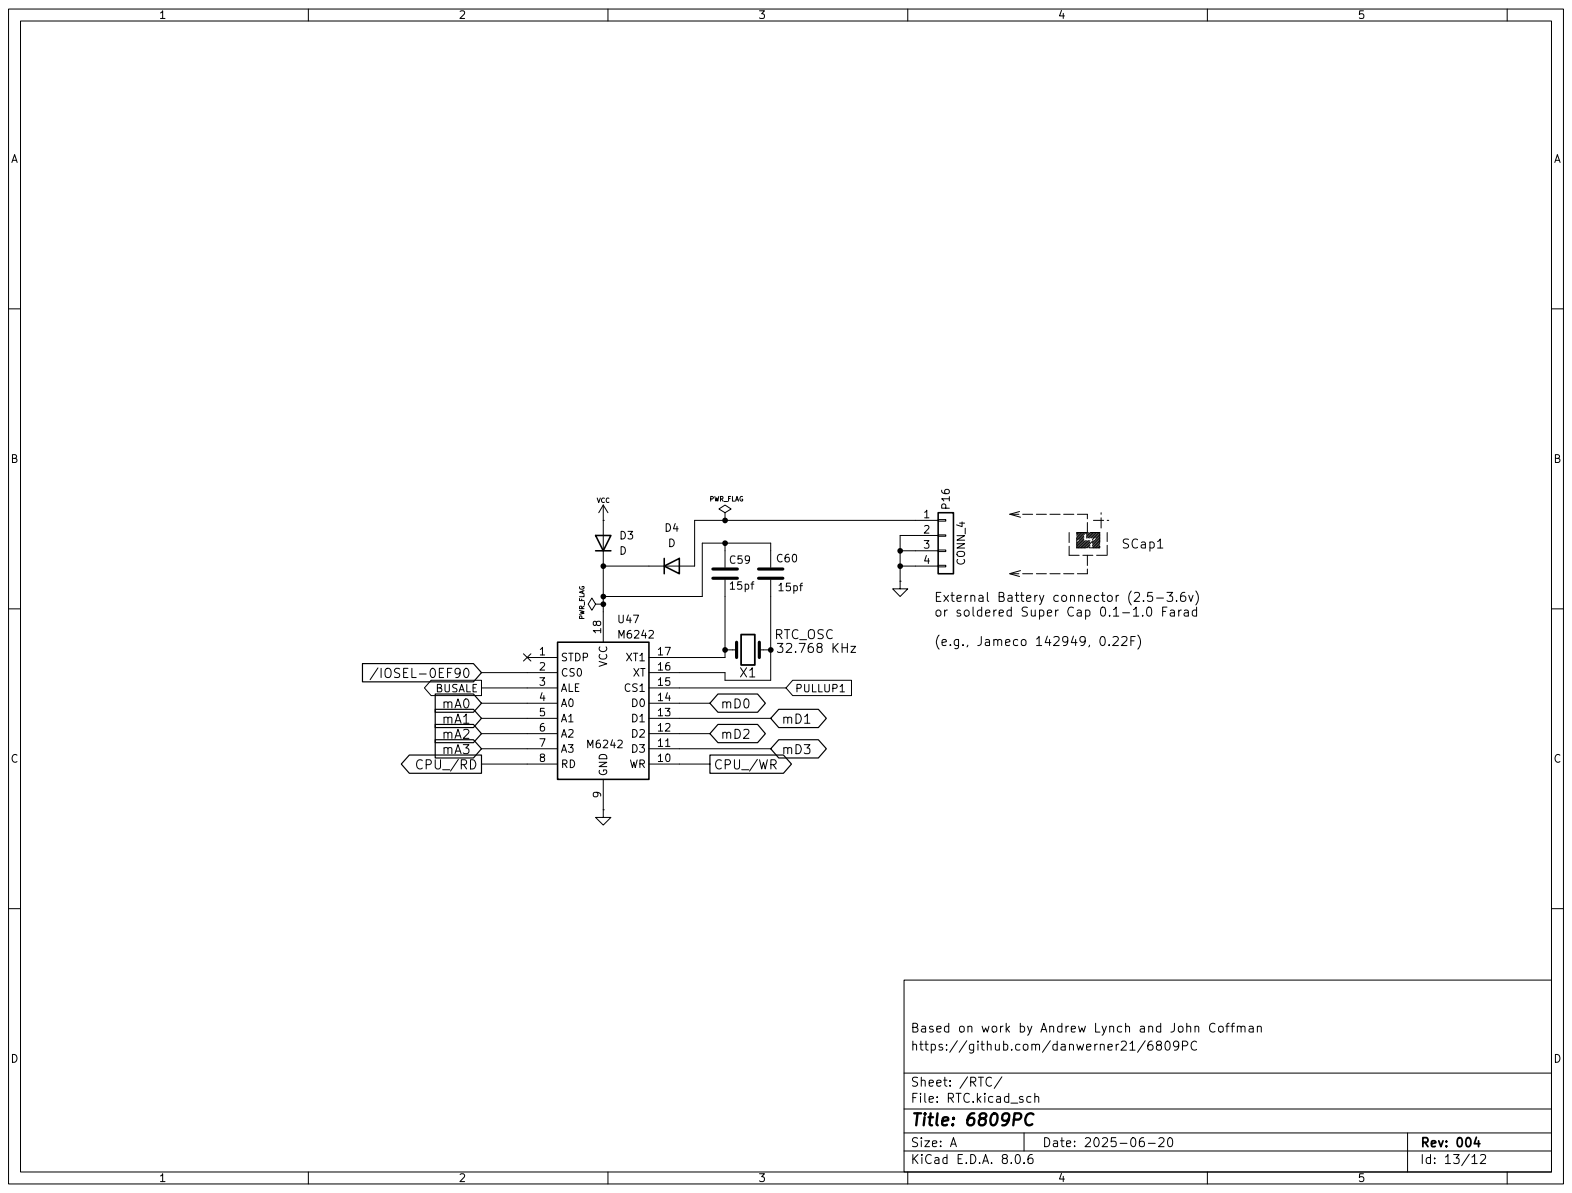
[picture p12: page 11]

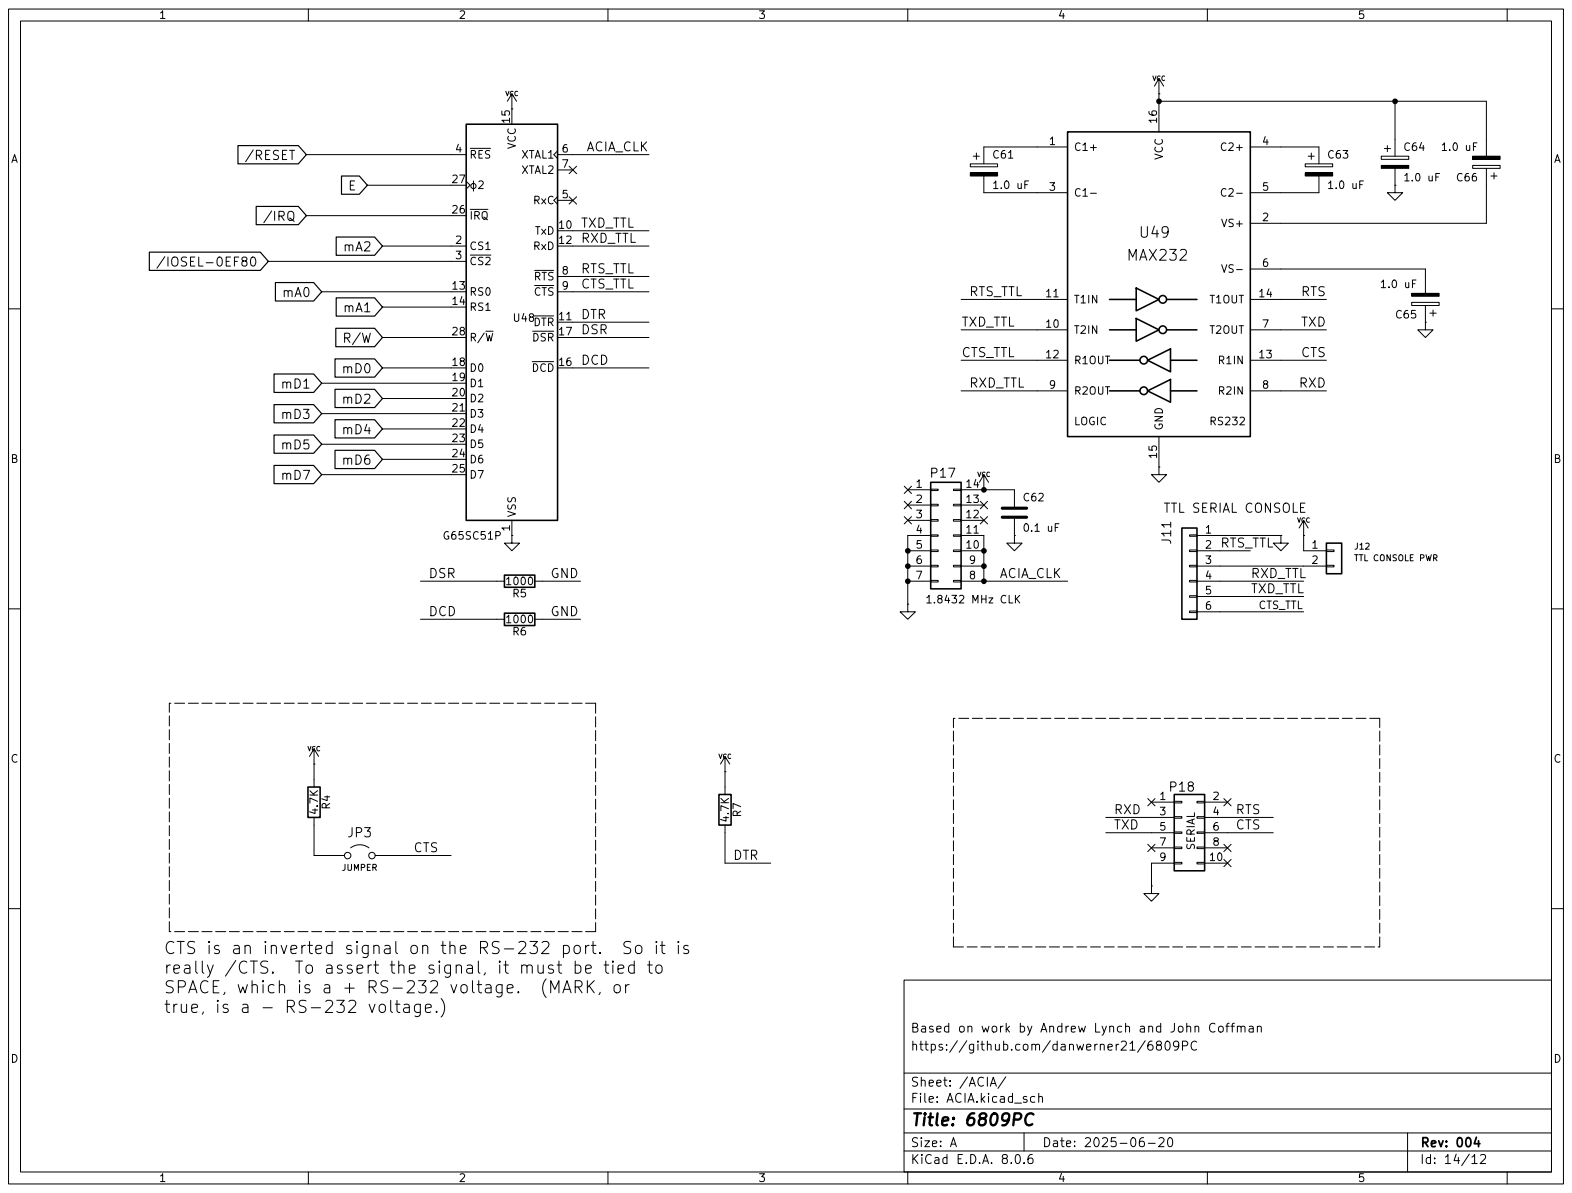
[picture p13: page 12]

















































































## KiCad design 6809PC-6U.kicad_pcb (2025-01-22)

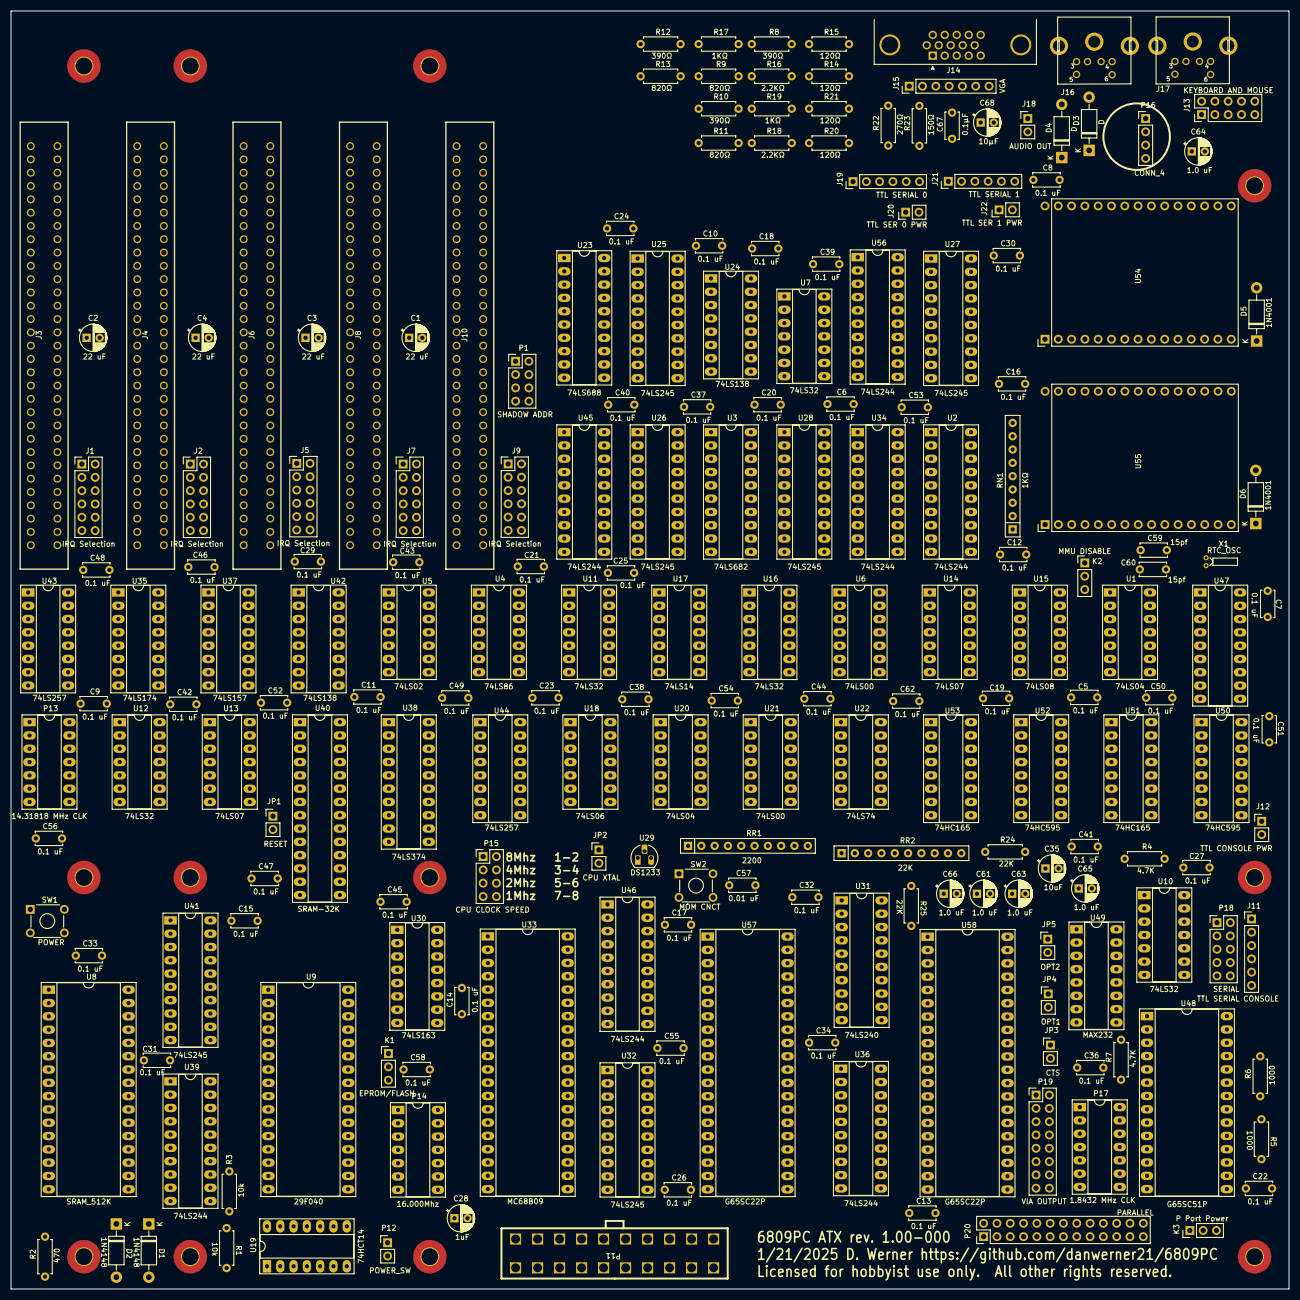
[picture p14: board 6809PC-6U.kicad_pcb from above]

Board: 2 copper layers, 244.0 x 244.0 mm, 216 parts (0 on the bottom side), 371 nets, no tracks yet.

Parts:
C1, C2, C3, C4: 22 uF; STD_DDW_PCAP
C5, C6, C7, C8, C9, C10, C11, C12, C13, C14, C15, C16, C17, C18, C19, C20, C21, C22, C23, C24, C25, C26, C27, C29, C30, C31, C32, C33, C34, C36, C37, C38, C39, C40, C41, C42, C43, C44, C45, C46, C47, C48, C49, C50, C51, C52, C53, C54, C55, C56, C58, C62: 0.1 uF; STD_DDW_CAP
C28: 1uF; STD_DDW_PCAP
C35: 10uF; STD_DDW_PCAP
C57: 0.01 uF; STD_DDW_CAP
C59, C60: 15pf; STD_DDW_CAP
C61, C63, C64, C65, C66: 1.0 uF; STD_DDW_PCAP
C67: 0.1µF; STD_DDW_CAP
C68: 10µF; STD_DDW_PCAP
D1, D2: 1N4148; STD_DDW_DIODE
D3, D4: D; STD_DDW_DIODE
D5, D6: 1N4001; STD_DDW_DIODE
J1, J2, J5, J7, J9: IRQ Selection; STD_DDW_PINHEAD_V_2x06
J3, J4, J6, J8, J10: Bus_ISA_8bit; BUSPC_HOST
J11: TTL SERIAL CONSOLE; STD_DDW_PINHEAD_V_1x06
J12: TTL CONSOLE PWR; STD_DDW_PINHEAD_V_1x02
J13: KEYBOARD AND MOUSE; STD_DDW_PINHEAD_V_2x05
J14: VGA; STD_DDW_VGA
J15: VGA; STD_DDW_PINHEAD_V_1x07
J16: Keyboard; PS2_DIN
J17: Mouse; PS2_DIN
J18: AUDIO OUT; STD_DDW_PINHEAD_V_1x02
J19: TTL SERIAL 0; STD_DDW_PINHEAD_V_1x06
J20: TTL SER 0 PWR; STD_DDW_PINHEAD_V_1x02
J21: TTL SERIAL 1; STD_DDW_PINHEAD_V_1x06
J22: TTL SER 1 PWR; STD_DDW_PINHEAD_V_1x02
JP1: RESET; STD_DDW_PINHEAD_V_1x02
JP2: CPU XTAL; STD_DDW_PINHEAD_V_1x02
JP3: CTS; STD_DDW_PINHEAD_V_1x02
JP4: OPT1; STD_DDW_PINHEAD_V_1x02
JP5: OPT2; STD_DDW_PINHEAD_V_1x02
K1: EPROM/FLASH; STD_DDW_PINHEAD_V_1x03
K2: MMU DISABLE; STD_DDW_PINHEAD_V_1x03
K3: P Port Power; STD_DDW_PINHEAD_V_1x03
P1: SHADOW ADDR; STD_DDW_PINHEAD_V_2x04
P2, P3, P4, P5, P6, P7, P8, P9, P10, P21, P22, P23: CONN_1; MountingHole_3.2mm_M3_Pad_TopBottom
P11: CONN_10X2; ATXConnector
P12: POWER_SW; STD_DDW_PINHEAD_V_1x02
P13: 14.31818 MHz CLK; STD_DDW_DIP14
P14: 16.000Mhz; STD_DDW_DIP14
P15: CPU CLOCK SPEED; STD_DDW_PINHEAD_V_2x04
P16: CONN_4; STD_DDW_PINHEAD_V_1x04
P17: 1.8432 MHz CLK; STD_DDW_DIP14
P18: SERIAL; STD_DDW_PINHEAD_V_2x05
P19: VIA OUTPUT; STD_DDW_PINHEAD_V_2x08
P20: PARALLEL; STD_DDW_PINHEAD_V_2x13
R1, R3: 10k; STD_DDW_RESISTOR
R2: 470; STD_DDW_RESISTOR
R4, R7: 4.7K; STD_DDW_RESISTOR
R5, R6: 1000; STD_DDW_RESISTOR
R8, R10, R12: 390Ω; STD_DDW_RESISTOR
R9, R11, R13: 820Ω; STD_DDW_RESISTOR
R14, R15, R20, R21: 120Ω; STD_DDW_RESISTOR
R16, R18: 2.2KΩ; STD_DDW_RESISTOR
R17, R19: 1KΩ; STD_DDW_RESISTOR
R22: 270Ω; STD_DDW_RESISTOR
R23: 150Ω; STD_DDW_RESISTOR
R24, R25: 22K; STD_DDW_RESISTOR
RN1: 1KΩ; STD_DDW_SIP9
RR1: 2200; STD_DDW_SIP10
RR2: 22K; STD_DDW_SIP10
SW1: POWER; STD_DDW_TACTSW
SW2: MOM CNCT; STD_DDW_TACTSW
U1, U20: 74LS04; STD_DDW_DIP14
U2, U34, U36, U39, U45, U46, U56: 74LS244; STD_DDW_DIP20
U3: 74LS682; STD_DDW_DIP20
U4: 74LS86; STD_DDW_DIP14
U5: 74LS02; STD_DDW_DIP14
U6, U21: 74LS00; STD_DDW_DIP14
U7, U10, U11, U12, U16: 74LS32; STD_DDW_DIP14
U8: SRAM_512K; STD_DDW_DIP32
U9: 29F040; STD_DDW_DIP32
U13, U14: 74LS07; STD_DDW_DIP14
U15: 74LS08; STD_DDW_DIP14
U17: 74LS14; STD_DDW_DIP14
U18: 74LS06; STD_DDW_DIP14
U19: 74HCT14; STD_DDW_DIP14
U22: 74LS74; STD_DDW_DIP14
U23: 74LS688; STD_DDW_DIP20
U24, U42: 74LS138; STD_DDW_DIP16
U25, U26, U27, U28, U32, U41: 74LS245; STD_DDW_DIP20
U29: DS1233; STD_DDW_TO92
U30: 74LS163; STD_DDW_DIP16
U31: 74LS240; STD_DDW_DIP20
U33: MC68B09; STD_DDW_DIP40
U35: 74LS174; STD_DDW_DIP16
U37: 74LS157; STD_DDW_DIP16
U38: 74LS374; STD_DDW_DIP20
U40: SRAM-32K; STD_DDW_DIP28_SKINNY
U43, U44: 74LS257; STD_DDW_DIP16
U47: STD_DDW_DIP18
U48: G65SC51P; STD_DDW_DIP28
U49: MAX232; STD_DDW_DIP16
U50, U52: 74HC595; STD_DDW_DIP16
U51, U53: 74HC165; STD_DDW_DIP16
U54, U55: ESP32_MODULE; ESP32_Module
U57, U58: G65SC22P; STD_DDW_DIP40
X1: RTC_OSC; DDW_STD_RTCCRYSTAL

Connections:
5VSB: D1.1 (K), D2.1 (K), P11.17, R1.1, R3.2, U19.9, U19.11, U19.13, U22.1 (~R)
+3V3: C8.1, C12.1, C16.1, C20.1, C24.1, P11.1, P11.2, P11.3, R16.2, R17.2, R18.2, R19.2, RN1.1 (common)
+12V: J3.9 (+12V), J4.9 (+12V), J6.9 (+12V), J8.9 (+12V), J10.9 (+12V), P11.19
-5V: J3.5 (-5V), J4.5 (-5V), J6.5 (-5V), J8.5 (-5V), J10.5 (-5V), P11.16
-12V: J3.7 (-12V), J4.7 (-12V), J6.7 (-12V), J8.7 (-12V), J10.7 (-12V), P11.4
/ACIA/ACIA_CLK: P17.8, P17.9, P17.10, P17.11, U48.6 (XTAL1)
/ACIA/CTS: JP3.2 (B), P18.6, U49.13 (R1IN)
/ACIA/CTS_TTL: U48.9 (~CTS), U49.12 (R1OUT)
/ACIA/DCD: R6.2, U48.16 (~DCD)
/ACIA/DSR: R5.2, U48.17 (~DSR)
/ACIA/DTR: R7.2, U48.11 (~DTR)
/ACIA/RTS: P18.4, U49.14 (T1OUT)
/ACIA/RTS_TTL: U48.8 (~RTS), U49.11 (T1IN)
/ACIA/RXD: P18.3, U49.8 (R2IN)
/ACIA/RXD_TTL: J11.4, U48.12 (RxD), U49.9 (R2OUT)
/ACIA/TXD: P18.5, U49.7 (T2OUT)
/ACIA/TXD_TTL: J11.5, U48.10 (TxD), U49.10 (T2IN)
/CPU 6809/1MHZ: P15.7, U30.11 (Q3)
/CPU 6809/2MHZ: P15.5, U30.12 (Q2)
/CPU 6809/4MHZ: P15.3, U30.13 (Q1)
/CPU 6809/8MHZ: P15.1, U30.14 (Q0)
/CPU 6809//INTA: K2.2, U21.3
/MMU four/MMU-ENABLE: U22.9 (Q), U36.2 (I0a), U37.1 (S), U43.1 (S), U44.1 (S)
/MMU four//MMU-ENB-WR: U22.11 (C), U42.13 (O2)
/MMU four//MMU-MAP-RD: U10.11, U15.1
/MMU four//MMU-MAP-WR: U10.8, U40.27 (~WE)
/MMU four//MMU-TASK-RD: U36.1 (OEa), U36.4 (I1a), U36.19 (OEb), U42.11 (O4)
/MMU four//MMU-TASK-SETUP-WR: U38.11 (Cp), U42.14 (O1)
/MMU four//MMU-TASK-WR: U35.9 (Cp), U42.15 (O0)
/MMU four//OE: U15.3, U40.22 (~OE)
/Memory Map/SHADOW-ROM: U5.10, U5.11
/Memory Map//SHADOW: U3.19 (~P=Q), U5.5, U5.9, U6.2
/VIAS/CA1: P19.3, U57.40 (CA1)
/VIAS/CA2: P19.5, U57.39 (CA2)
/VIAS/CB1: P19.7, U57.18 (CB1)
/VIAS/CB2: P19.9, U57.19 (CB2)
/VIAS/CC1: P19.11, U58.40 (CA1)
/VIAS/CC2: P19.13, U58.39 (CA2)
/VIAS/PA0: P20.2, U57.2 (PA0)
/VIAS/PA1: P20.4, U57.3 (PA1)
/VIAS/PA2: P20.6, U57.4 (PA2)
/VIAS/PA3: P20.8, U57.5 (PA3)
/VIAS/PA4: P20.10, U57.6 (PA4)
/VIAS/PA5: P20.12, U57.7 (PA5)
/VIAS/PA6: P20.14, U57.8 (PA6)
/VIAS/PA7: P20.16, U57.9 (PA7)
/VIAS/PB0: P20.18, U57.10 (PB0)
/VIAS/PB1: P20.20, U57.11 (PB1)
/VIAS/PB2: P20.22, U57.12 (PB2)
/VIAS/PB3: P20.24, U57.13 (PB3)
/VIAS/PB4: P20.23, U57.14 (PB4)
/VIAS/PB5: P20.21, U57.15 (PB5)
/VIAS/PB6: P20.19, U57.16 (PB6)
/VIAS/PB7: P20.17, U57.17 (PB7)
/VIAS/PC0: P20.1, U58.2 (PA0)
/VIAS/PC1: P20.3, U58.3 (PA1)
/VIAS/PC2: P20.5, U58.4 (PA2)
/VIAS/PC3: P20.7, U58.5 (PA3)
/VIAS/PC4: P20.9, U58.6 (PA4)
/VIAS/PC5: P20.11, U58.7 (PA5)
/VIAS/PC6: P20.13, U58.8 (PA6)
/VIAS/PC7: P20.15, U58.9 (PA7)
/VIAS/PPWR: K3.2, P20.25
AUDIO: R22.1, U54.8 (GPIO25)
BUSAK: U4.9, U17.4, U32.19 (CE), U34.1 (OEa), U43.15 (OE), U44.15 (OE), U45.19 (OEb), U46.1 (OEa), U46.19 (OEb)
BUSALE: J3.28 (ALE), J4.28 (ALE), J6.28 (ALE), J8.28 (ALE), J10.28 (ALE), U17.2, U47.3 (ALE)
BUSCLK: J3.30 (OSC), J4.30 (OSC), J6.30 (OSC), J8.30 (OSC), J10.30 (OSC), P13.8, P13.9, P13.10, P13.11
B_A0: J3.62 (BA00), J4.62 (BA00), J6.62 (BA00), J8.62 (BA00), J10.62 (BA00), U26.18 (B0)
B_A1: J3.61 (BA01), J4.61 (BA01), J6.61 (BA01), J8.61 (BA01), J10.61 (BA01), U26.17 (B1)
B_A2: J3.60 (BA02), J4.60 (BA02), J6.60 (BA02), J8.60 (BA02), J10.60 (BA02), U26.16 (B2)
B_A3: J3.59 (BA03), J4.59 (BA03), J6.59 (BA03), J8.59 (BA03), J10.59 (BA03), U26.15 (B3)
B_A4: J3.58 (BA04), J4.58 (BA04), J6.58 (BA04), J8.58 (BA04), J10.58 (BA04), U26.14 (B4)
B_A5: J3.57 (BA05), J4.57 (BA05), J6.57 (BA05), J8.57 (BA05), J10.57 (BA05), U26.13 (B5)
B_A6: J3.56 (BA06), J4.56 (BA06), J6.56 (BA06), J8.56 (BA06), J10.56 (BA06), U26.12 (B6)
B_A7: J3.55 (BA07), J4.55 (BA07), J6.55 (BA07), J8.55 (BA07), J10.55 (BA07), U26.11 (B7)
B_A8: J3.54 (BA08), J4.54 (BA08), J6.54 (BA08), J8.54 (BA08), J10.54 (BA08), U27.18 (B0)
B_A9: J3.53 (BA09), J4.53 (BA09), J6.53 (BA09), J8.53 (BA09), J10.53 (BA09), U27.17 (B1)
B_A10: J3.52 (BA10), J4.52 (BA10), J6.52 (BA10), J8.52 (BA10), J10.52 (BA10), U27.16 (B2)
B_A11: J3.51 (BA11), J4.51 (BA11), J6.51 (BA11), J8.51 (BA11), J10.51 (BA11), U27.15 (B3)
B_A12: J3.50 (BA12), J4.50 (BA12), J6.50 (BA12), J8.50 (BA12), J10.50 (BA12), U27.14 (B4)
B_A13: J3.49 (BA13), J4.49 (BA13), J6.49 (BA13), J8.49 (BA13), J10.49 (BA13), U27.13 (B5)
B_A14: J3.48 (BA14), J4.48 (BA14), J6.48 (BA14), J8.48 (BA14), J10.48 (BA14), U27.12 (B6)
B_A15: J3.47 (BA15), J4.47 (BA15), J6.47 (BA15), J8.47 (BA15), J10.47 (BA15), U27.11 (B7)
B_A16: J3.46 (BA16), J4.46 (BA16), J6.46 (BA16), J8.46 (BA16), J10.46 (BA16), U28.18 (B0)
B_A17: J3.45 (BA17), J4.45 (BA17), J6.45 (BA17), J8.45 (BA17), J10.45 (BA17), U28.17 (B1)
B_A18: J3.44 (BA18), J4.44 (BA18), J6.44 (BA18), J8.44 (BA18), J10.44 (BA18), U28.16 (B2)
B_A19: J3.43 (BA19), J4.43 (BA19), J6.43 (BA19), J8.43 (BA19), J10.43 (BA19), U28.15 (B3)
B_D0: J3.40 (DB0), J4.40 (DB0), J6.40 (DB0), J8.40 (DB0), J10.40 (DB0), U25.18 (B0)
B_D1: J3.39 (DB1), J4.39 (DB1), J6.39 (DB1), J8.39 (DB1), J10.39 (DB1), U25.17 (B1)
B_D2: J3.38 (DB2), J4.38 (DB2), J6.38 (DB2), J8.38 (DB2), J10.38 (DB2), U25.16 (B2)
B_D3: J3.37 (DB3), J4.37 (DB3), J6.37 (DB3), J8.37 (DB3), J10.37 (DB3), U25.15 (B3)
B_D4: J3.36 (DB4), J4.36 (DB4), J6.36 (DB4), J8.36 (DB4), J10.36 (DB4), U25.14 (B4)
B_D5: J3.35 (DB5), J4.35 (DB5), J6.35 (DB5), J8.35 (DB5), J10.35 (DB5), U25.13 (B5)
B_D6: J3.34 (DB6), J4.34 (DB6), J6.34 (DB6), J8.34 (DB6), J10.34 (DB6), U25.12 (B6)
B_D7: J3.33 (DB7), J4.33 (DB7), J6.33 (DB7), J8.33 (DB7), J10.33 (DB7), U25.11 (B7)
B_INT: J1.1, J1.2, J1.3, J1.4, J1.5, J1.6, J2.1, J2.2, J2.3, J2.4, J2.5, J2.6, J5.1, J5.2, J5.3, J5.4, J5.5, J5.6, J7.1, J7.2, J7.3, J7.4, J7.5, J7.6, J9.1, J9.2, J9.3, J9.4, J9.5, J9.6, U18.13
B_/CLK: J3.20 (CLK), J4.20 (CLK), J6.20 (CLK), J8.20 (CLK), J10.20 (CLK), U31.18 (O0a)
B_/INT: RR1.2 (R1), U18.12, U31.6 (I2a)
B_/IORQ: U7.12, U16.4, U34.5 (O2b)
B_/MREQ: U16.1, U16.9, U28.12 (B6)
B_/NMI: J3.32 (IO), J4.32 (IO), J6.32 (IO), J8.32 (IO), J10.32 (IO), RR1.9 (R8), U31.4 (I1a)
B_/RD: U16.5, U16.10, U28.14 (B4)
B_/WR: U7.13, U16.2, U28.13 (B5)
CD1: JP4.2 (B), R24.2, U58.18 (CB1)
CD2: JP5.2 (B), R25.2, U58.19 (CB2)
CLK: P15.2, P15.4, P15.6, P15.8, U31.2 (I0a), U33.38 (EXTAL)
CPU_BA: U1.11, U33.6 (BA)
CPU_BS: RR2.10 (R9), U21.2, U33.5 (BS)
CPU_D0: U32.18 (B0), U33.31 (D0)
CPU_D1: U32.17 (B1), U33.30 (D1)
CPU_D2: U32.16 (B2), U33.29 (D2)
CPU_D3: U32.15 (B3), U33.28 (D3)
CPU_D4: U32.14 (B4), U33.27 (D4)
CPU_D5: U32.13 (B5), U33.26 (D5)
CPU_D6: U32.12 (B6), U33.25 (D6)
CPU_D7: U32.11 (B7), U33.24 (D7)
CPU_E: U5.2, U6.10, U33.34 (E), U34.17 (I3b), U45.6 (I2a)
CPU_Q: U5.3, U17.1, U33.35 (Q), U45.4 (I1a)
CPU_R/W: U1.1, U6.5, U33.32 (R/~W), U34.8 (I3a), U45.8 (I3a)
CPU_/RD: U6.6, U10.13, U12.10, U12.13, U16.13, U34.4 (I1a), U47.8 (RD)
CPU_/WR: U6.8, U10.9, U12.2, U12.5, U34.6 (I2a), U47.10 (WR)
E: U6.4, U34.3 (O3b), U42.6 (E3), U45.14 (O2a), U48.27 (ϕ2), U57.25 (ϕ2), U58.25 (ϕ2)
ESP0_BUSY: U54.11 (GPIO14), U56.4 (I1a)
ESP0_IN: RN1.7 (R6), U14.12, U54.22 (GPIO17)
ESP0_INCLK: U53.2 (CP), U54.10 (GPIO27)
ESP0_OUT: U52.14 (SER), U54.21 (GPIO16)
ESP0_OUTCLK: U52.11 (SRCLK), U52.12 (RCLK), U54.9 (GPIO26)
ESP0_RDYO: U54.12 (GPIO12), U56.2 (I0a)
ESP0_SEL: U11.6, U12.1, U12.9
ESP0_SPAREO: U54.19 (GPIO2), U56.6 (I2a)
ESP1_BUSY: U55.24 (GPIO18), U56.11 (I0b)
ESP1_IN: RN1.2 (R1), U14.10, U55.22 (GPIO17)
ESP1_INCLK: U51.2 (CP), U55.25 (GPIO19)
ESP1_OUT: U50.14 (SER), U55.21 (GPIO16)
ESP1_OUTCLK: U50.11 (SRCLK), U50.12 (RCLK), U55.26 (GPIO21)
ESP1_RDYO: U55.23 (GPIO5), U56.8 (I3a)
ESP1_SEL: U11.8, U12.4, U12.12
ESPSTAT_SEL: U11.11, U16.12
GND: C1.2, C2.2, C3.2, C4.2, C5.2, C6.2, C7.2, C8.2, C9.2, C10.2, C11.2, C12.2, C13.2, C14.2, C15.2, C16.2, C17.2, C18.2, C19.2, C20.2, C21.2, C22.2, C23.2, C24.2, C25.2, C26.2, C27.2, C28.2, C29.2, C30.2, C31.2, C32.2, C33.2, C34.2, C35.2, C36.2, C37.2, C38.2, C39.2, C40.2, C41.2, C42.2, C43.2, C44.2, C45.2, C46.2, C47.2, C48.2, C49.2, C50.2, C51.2, C52.2, C53.2, C54.2, C55.2, C56.2, C57.2, C58.2, C62.2, C64.2, C65.1, C67.2, J3.1 (GND), J3.10 (GND), J3.31 (GND), J4.1 (GND), J4.10 (GND), J4.31 (GND), J6.1 (GND), J6.10 (GND), J6.31 (GND), J8.1 (GND), J8.10 (GND), J8.31 (GND), J10.1 (GND), J10.10 (GND), J10.31 (GND), J11.1, J13.1, J13.3, J13.8, J13.10, J14.0, J14.5, J14.6, J14.7, J14.8, J14.10, J15.7, J16.3, J17.3, J18.2, J19.1, J21.1, JP1.2, JP2.1 (A), JP4.1 (A), JP5.1 (A), K3.1, P1.1, P1.3, P1.5, P1.7, P2.1, P3.1, P4.1, P5.1, P6.1, P7.1, P8.1, P9.1, P10.1, P11.5, P11.6, P11.9, P11.10, P11.12, P11.13, P11.14, P12.1, P13.4, P13.5, P13.6, P13.7, P14.4, P14.5, P14.6, P14.7, P16.2, P16.3, P16.4, P17.4, P17.5, P17.6, P17.7, P18.9, P19.15, P20.26, P21.1, P22.1, P23.1, R5.1, R6.1, R23.2, SW1.1, SW2.1, U1.7 (GND), U2.10 (GND), U2.17 (I3b), U3.10 (GND), U3.17 (P7), U3.18 (Q7), U4.7 (GND), U5.7 (GND), U6.7 (GND), U7.7 (GND), U8.16 (VSS), U9.16 (GND), U10.7 (GND), U11.7 (GND), U12.7 (GND), U13.7 (GND), U14.7 (GND), U15.7 (GND), U16.7 (GND), U17.7 (GND), U18.7 (GND), U19.7 (GND), U20.7 (GND), U21.7 (GND), U22.7 (GND), U23.10 (GND), U24.16 (VCC), U25.10 (GND), U25.19 (CE), U26.10 (GND), U26.19 (CE), U27.10 (GND), U27.19 (CE), U28.10 (GND), U28.19 (CE), U29.1, U30.8 (GND), U31.1 (OEa), U31.10 (GND), U32.10 (GND), U33.1 (VSS), U34.10 (GND), U34.19 (OEb), U35.8 (GND), U36.10 (GND), U37.8 (GND), U37.15 (E), U38.10 (GND), U39.10 (GND), U40.14 (GND), U40.20 (~CS), U41.10 (GND), U42.16 (VCC), U43.8 (GND), U44.8 (GND), U45.1 (OEa), U45.10 (GND), U46.10 (GND), U47.9 (GND), U48.1 (VSS), U49.15 (GND), U50.8 (GND), U51.8 (GND), U51.15 (~CE), U52.8 (GND), U53.8 (GND), U53.15 (~CE), U54.14 (GND), U54.17 (GND), U55.14 (GND), U55.17 (GND), U56.10 (GND), U56.13 (I1b), U56.15 (I2b), U56.17 (I3b), U57.1 (VSS), U58.1 (VSS)
IOR: J3.14 (~IOR), J4.14 (~IOR), J6.14 (~IOR), J8.14 (~IOR), J10.14 (~IOR), U16.8
IOW: J3.13 (~IOW), J4.13 (~IOW), J6.13 (~IOW), J8.13 (~IOW), J10.13 (~IOW), U16.6
KBDCLK: R20.2, U54.7 (GPIO33)
KBDDAT: R21.2, U54.6 (GPIO32)
LA0: U33.8 (A0), U45.11 (I0b)
LA1: U33.9 (A1), U45.13 (I1b)
LA2: U33.10 (A2), U45.15 (I2b)
LA3: U33.11 (A3), U45.17 (I3b)
LA4: U33.12 (A4), U46.2 (I0a)
LA5: U33.13 (A5), U46.4 (I1a)
LA6: U33.14 (A6), U46.6 (I2a)
LA7: U33.15 (A7), U46.8 (I3a)
LA8: U33.16 (A8), U46.11 (I0b)
LA9: U33.17 (A9), U46.13 (I1b)
LA10: U33.18 (A10), U46.15 (I2b)
LA11: U33.19 (A11), U46.17 (I3b)
LA12: U33.20 (A12), U37.3 (I1a), U43.2 (I0a)
LA13: U33.21 (A13), U37.6 (I1b), U43.5 (I0b)
LA14: U33.22 (A14), U37.10 (I1c), U43.14 (I0c)
LA15: U33.23 (A15), U37.13 (I1d), U43.11 (I0d)
MRDY: RR2.3 (R2), U33.36 (MRDY)
MSECLK: R15.1, U55.7 (GPIO33)
MSEDAT: R14.1, U55.6 (GPIO32)
unnamed: C67.1, C68.1, R22.2, R23.1
unnamed: C28.1, D1.2 (A), R2.1, U19.3
unnamed: C35.1, D2.2 (A), R3.1, U19.1
unnamed: C59.1, C60.1, D3.1 (K), D4.1 (K), U47.18 (VCC)
unnamed: D4.2 (A), P16.1
unnamed: D5.1 (K), U54.15 (VIN)
unnamed: D6.1 (K), U55.15 (VIN)
unnamed: J1.8, J3.25 (IRQ3)
unnamed: J1.9, J3.24 (IRQ4)
unnamed: J1.10, J3.23 (IRQ5)
unnamed: J1.11, J3.22 (IRQ6)
unnamed: J1.12, J3.21 (IRQ7)
unnamed: J2.8, J4.25 (IRQ3)
unnamed: J2.9, J4.24 (IRQ4)
unnamed: J2.10, J4.23 (IRQ5)
unnamed: J2.11, J4.22 (IRQ6)
unnamed: J2.12, J4.21 (IRQ7)
unnamed: J5.8, J6.25 (IRQ3)
unnamed: J5.9, J6.24 (IRQ4)
unnamed: J5.10, J6.23 (IRQ5)
unnamed: J5.11, J6.22 (IRQ6)
unnamed: J5.12, J6.21 (IRQ7)
unnamed: J7.8, J8.25 (IRQ3)
unnamed: J7.9, J8.24 (IRQ4)
unnamed: J7.10, J8.23 (IRQ5)
unnamed: J7.11, J8.22 (IRQ6)
unnamed: J7.12, J8.21 (IRQ7)
unnamed: J9.8, J10.25 (IRQ3)
unnamed: J9.9, J10.24 (IRQ4)
unnamed: J9.10, J10.23 (IRQ5)
unnamed: J9.11, J10.22 (IRQ6)
unnamed: J9.12, J10.21 (IRQ7)
unnamed: J11.3, J12.2
unnamed: J13.2, J16.5, R19.1, R20.1
unnamed: J13.4, J16.1, R18.1, R21.1
unnamed: J13.7, J17.1, R14.2, R16.1
unnamed: J13.9, J17.5, R15.2, R17.1
unnamed: J14.1, J15.3, R8.2, R9.2
unnamed: J14.2, J15.4, R10.2, R11.2
unnamed: J14.3, J15.5, R12.2, R13.2
unnamed: C68.2, J18.1
unnamed: J19.3, J20.2
unnamed: J21.3, J22.2
unnamed: JP2.2 (B), U33.39 (XTAL)
unnamed: JP3.1 (A), R4.2
unnamed: P12.2, R1.2, R2.2, SW1.2
unnamed: U1.6, U4.1
unnamed: U1.8, U5.8
unnamed: U1.12, U21.5
unnamed: U4.3, U6.1
unnamed: U4.6, U5.12
unnamed: U5.13, U7.1
unnamed: U6.3, U7.5
unnamed: U7.6, U8.22 (CE#)
unnamed: U7.3, U9.22 (CE)
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

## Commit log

2025-01-21 Schematic in progress
    [6809PC-6U.kicad_pcb, 6809PC-6U.kicad_sch, ACIA.kicad_sch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]
2025-01-22 PCB in progress
    [6809PC-6U.kicad_pcb, 6809PC-6U.kicad_sch, ACIA.kicad_sch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]
2025-05-18 6809PC work
    [6809PC-6U-B_Cu.gbl, 6809PC-6U-B_Mask.gbs, 6809PC-6U-B_Silkscreen.gbo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]
2025-05-19 fix issue with ISA RW select lines
    [6809PC-6U-B_Cu.gbl, 6809PC-6U-B_Mask.gbs, 6809PC-6U-B_Silkscreen.gbo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]
2025-06-02 fix bus issue
    [6809PC-6U-B_Cu.gbl, 6809PC-6U-B_Mask.gbs, 6809PC-6U-B_Silkscreen.gbo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]
2025-06-21 fix power supply switch circuit
    [6809PC-6U-B_Cu.gbl, 6809PC-6U-B_Mask.gbs, 6809PC-6U-B_Silkscreen.gbo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]
2025-07-06 isa work
    [6809PC-6U-B_Cu.gbl, 6809PC-6U-B_Mask.gbs, 6809PC-6U-B_Silkscreen.gbo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]

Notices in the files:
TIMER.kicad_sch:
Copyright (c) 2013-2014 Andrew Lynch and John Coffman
